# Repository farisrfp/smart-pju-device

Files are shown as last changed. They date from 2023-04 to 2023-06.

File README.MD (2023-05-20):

# **SMART PJU X-CAMP**

_Created by [Faris Rafi](https://www.linkedin.com/in/farisrafp/), last updated on 20 May 2023_

## **About SMART PJU**

This Smart PJU is a continuation of X-Bright with the addition of new features such as communication using LoRa, the use of new sensors, and the use of new modules. This Smart PJU also uses the concept of IoT (Internet of Things) which allows users to control this street lamp through the dashboard provided.

### **Wiring Diagram**

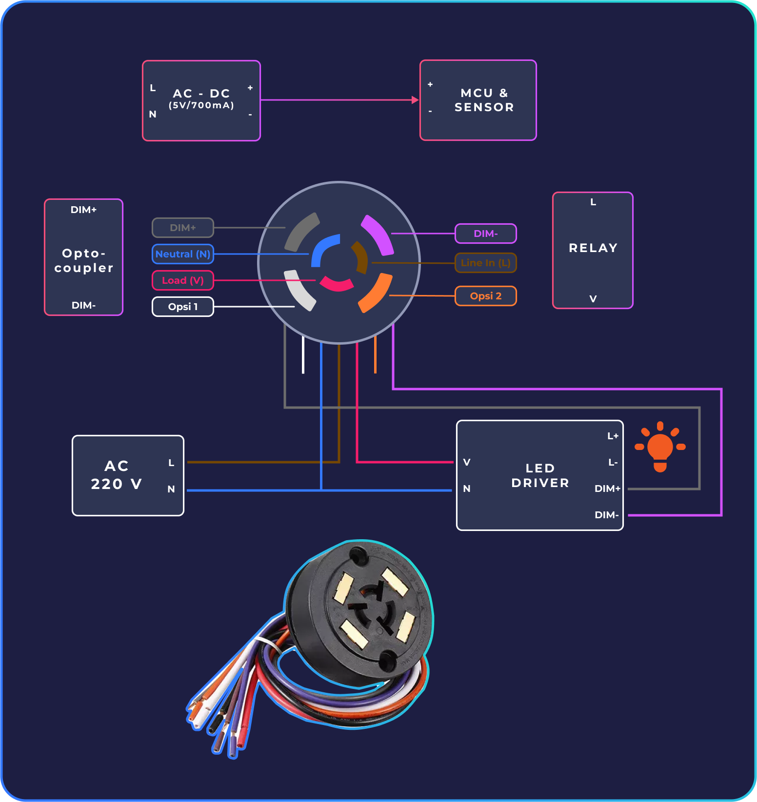
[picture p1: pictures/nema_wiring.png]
wiring


### **Hardware**

|               Controller V2               |
| :---------------------------------------: |
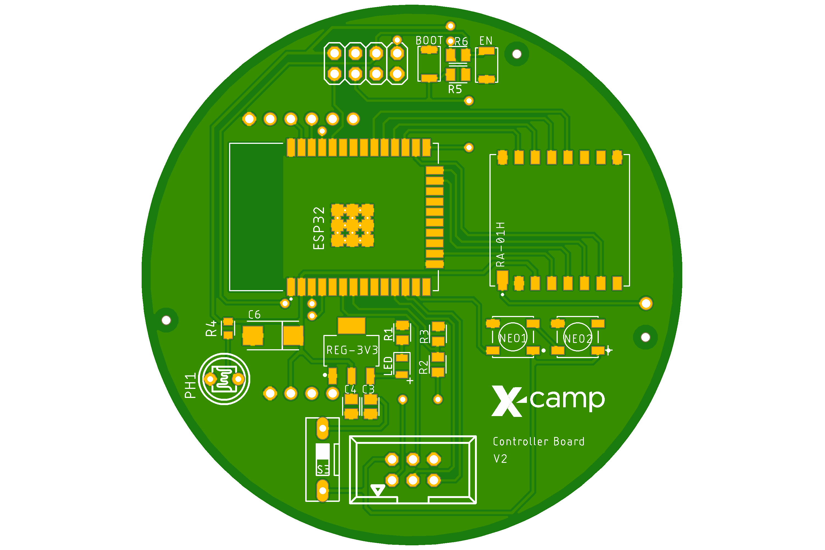
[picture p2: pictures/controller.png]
controller
|  |

|            Power V2             |
| :-----------------------------: |
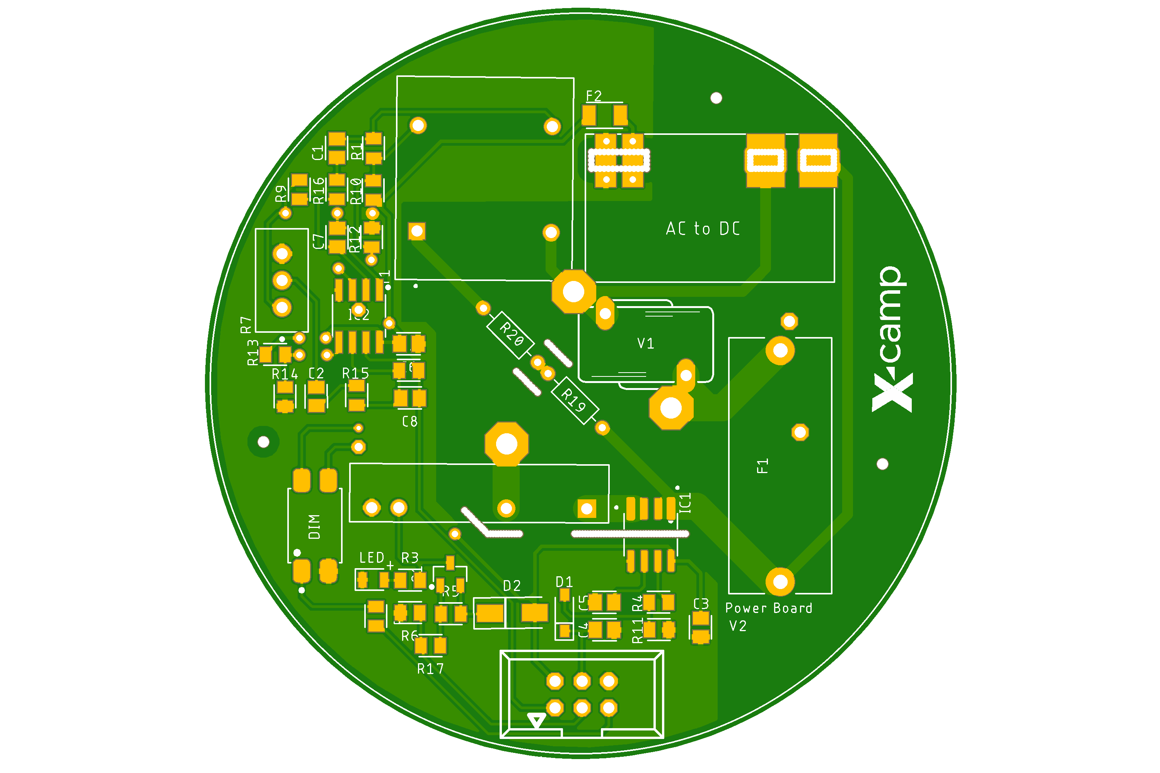
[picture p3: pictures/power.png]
power
|  |

Documentation can be seen [here](./hardware/)

### **Firmware**

Here is the sensor diagram and pinout used on Controller V2.

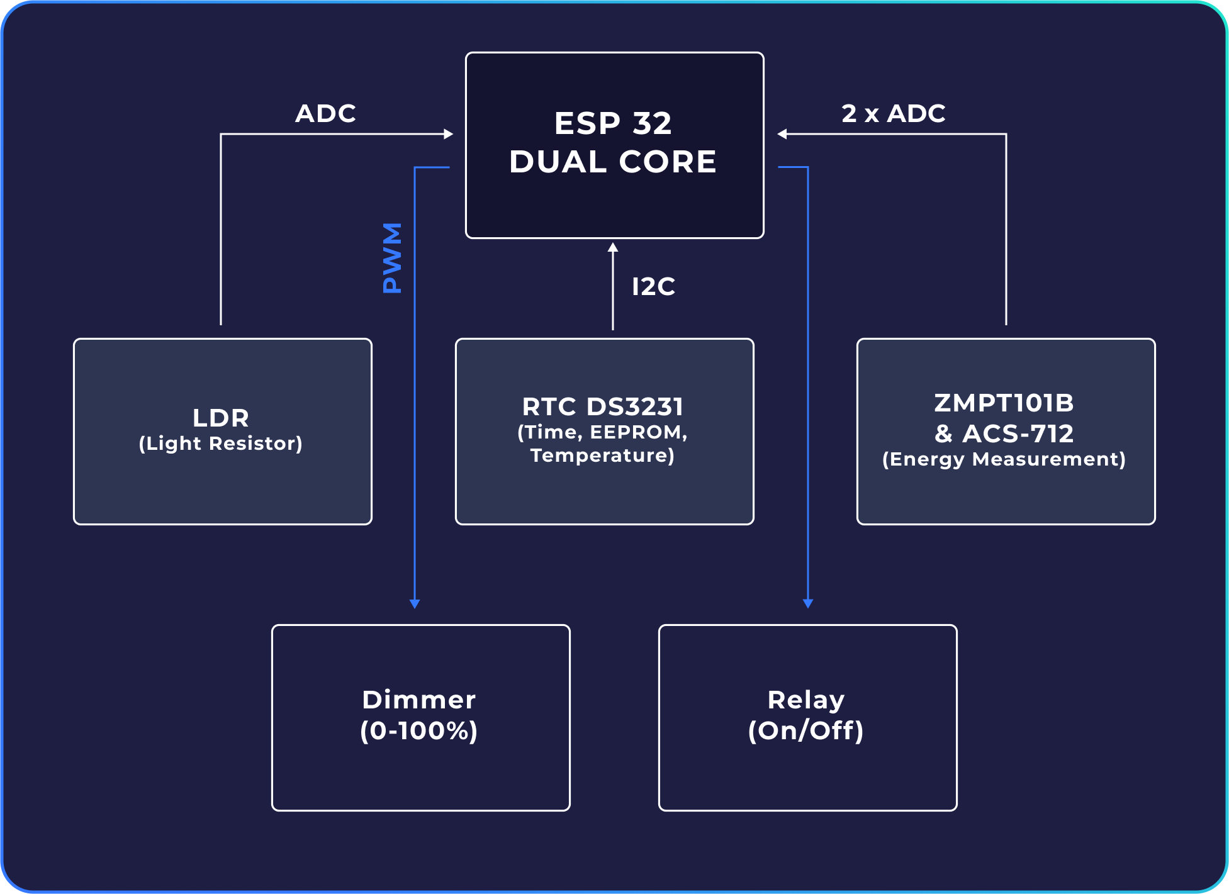
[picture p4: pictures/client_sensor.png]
sensor


Documentation can be seen [here](./firmware/)

## **Contact**

If you have any questions, please contact Faris, the product's designer, by E-mail.

Email : farisrafp@gmail.com

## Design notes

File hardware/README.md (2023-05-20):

# **Hardware Documentation**

## **BOM**

The BoM (Bill of Material) for this project can be seen in the table below.

### **Power Board**

| Designator | Quantity | Description |
| :---: | :---: | :---: |
| AC-DC | 1 |  AC to DC |
| V1 | 1 |  Varistor |
| F1 | 1 | Fuse Holder |
| F2 | 1 |  Fuse PTC |
| DIM | 1 | PC817 |
| IC1 | 1 | ACS712-05B  |
| IC2 | 1 | LM358N |
| T1 | 1 |  ZMPT101B |
| SSR | 1 |  G3MB-202P  |

**Passive Components**

| Designator | Quantity |  Package  |  Value  |
| :---: | :---: | :---: | :-----: |
| Q1 | 1 |  SOT-23 | SS8550  |
| D1 | 1 |  SOD-123  | 1N4448W |
| D2 | 1 | DO-214AC  | M4 |
| LED | 1 | 0805 |  Blue |
| R7 | 1 | 3296 |  100K |
| R1 | 1 | 0805 | 100 |
| R2 - 3 | 2 | 0805 | 330 |
| R4 | 1 | 0805 | 2K |
| R5 - 6 | 2 | 0805 |  4,7K |
| R8 - 9 | 2 | 0805 |  100K |
|  R10 - 17  | 8 | 0805 | 10K |
|  R19 - 20  | 2 | Axial-7.2 |  330K |
| C1 - 2 | 2 | 0805 | 1u |
| C3 - 4 | 2 | 0805 |  100n |
| C5 - 8 | 4 | 0805 | 1n |

<br>

### **Controller Board**

| Designator | Quantity | Description |
| :---: | :---: | :---: |
| ESP32 | 1 | ESP32-WROOM |
|  REG-3V3 | 1 | AMS1117-3V3 |
| RA-01H | 1 | AI-Thinker RA-01H |
| DS3231 | 1 | RTC DS3231 Module |
| NEO 1 | 2 | WS2812B |
| S1 - 2 | 2 | Micro Button |
| S3 | 1 | DIP Switch |
| PH1 | 1 | Light Dependent Resistor |

**Passive Components**

| Designator | Quantity | Package | Value |
| :---: | :---: | :-----: | :---: |
| LED | 1 |  0805 |  Red  |
| R1 - 2 | 2 |  0805 |  1K |
| R3 | 1 |  0805 |  2K |
| R4 - 6 | 3 |  0805 |  10K  |
| C1 | 1 |  0805 | 100n  |
| C2 | 1 |  0805 |  1u |
| C3 - 4 | 2 |  0805 |  10u  |
| C6 | 1 |  2412 | 100u  |

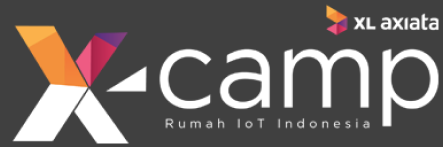
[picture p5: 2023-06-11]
firmware/interface/src/assets/xcamp.png

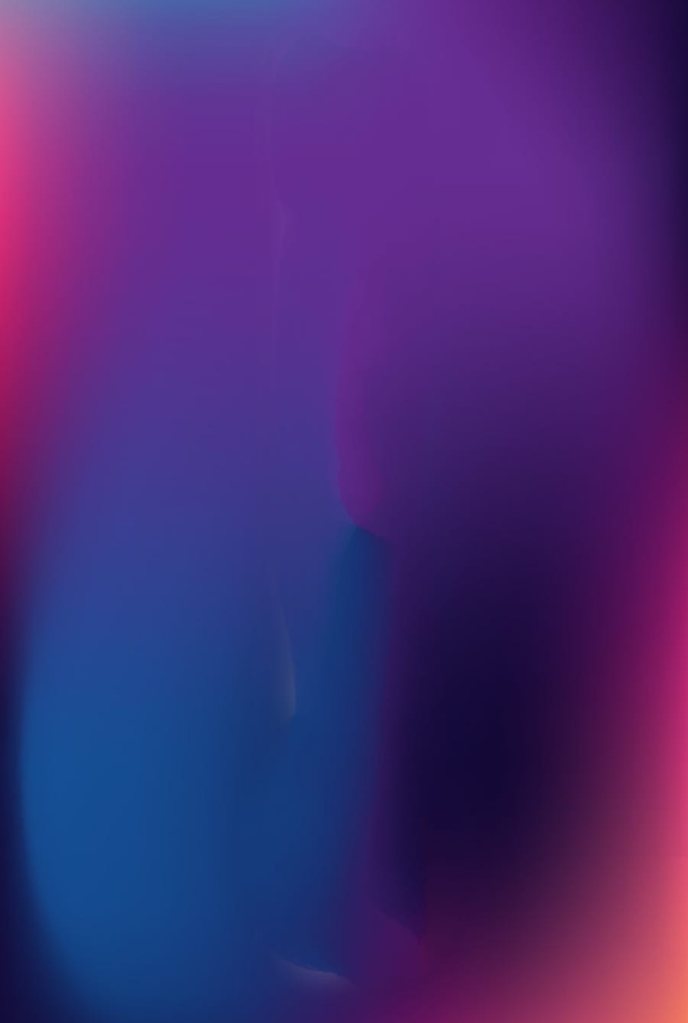
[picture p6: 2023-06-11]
firmware/interface/src/assets/background.png

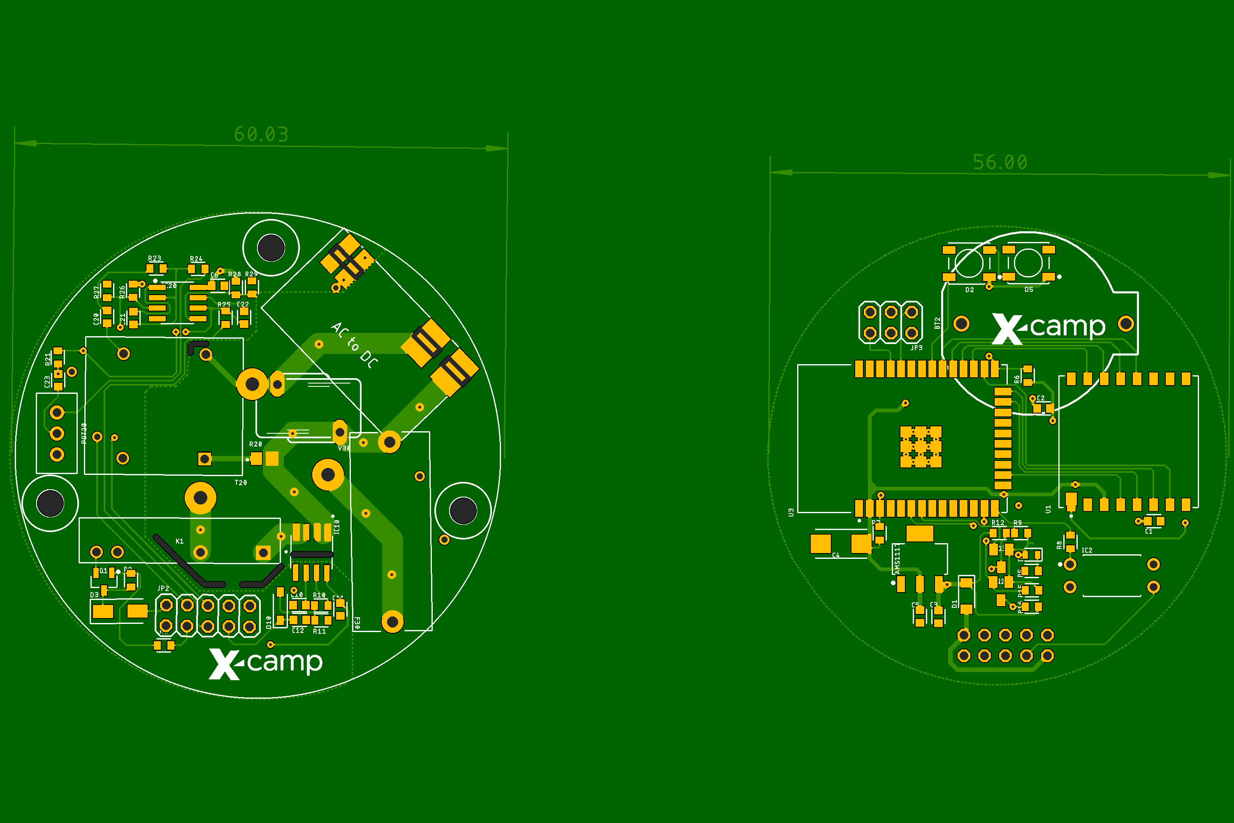
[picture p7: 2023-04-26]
pictures/board_v1.png

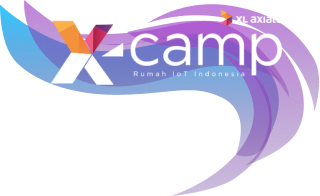
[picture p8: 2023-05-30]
firmware/interface/src/pages/xcamp2.png

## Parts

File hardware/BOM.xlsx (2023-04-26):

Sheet: BOM_Power
No | Designator | Komponen | Value | Package | Qty | Harga | Toko | Link
1 | PS1 | AC to DC | 5V to 700mA | wx-dc12003 | 1 | 14900 | Freelab | Jual 5V 700mA (3.5W) Isolated switch Power Supply Module AC DC 220V to 5V - Standar - Jakarta Pusat - Freelab | Tokopedia (https://www.tokopedia.com/freelab/5v-700ma-3-5w-isolated-switch-power-supply-module-ac-dc-220v-to-5v-pinout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)
2 | V30 | Varistor | 10D471K | Disc | 1 | 1500 | Freelab | Jual Varistor 10D471K MOV 10D471 470V Metal Voltage Dependent Resistor - - Freelab | Tokopedia (https://www.tokopedia.com/freelab/varistor-10d471k-mov-10d471-470v-metal-voltage-dependent-resistor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)
3 | F30 | Fuse Holder | - | 5 x 20 | 1 | 2500 | EasyWare Electronics | Jual Fuse Holder PCB 5x20 Fuse Holder BF-012 10A 250V - Kota Bandung - EasyWare Electronics | Tokopedia (https://www.tokopedia.com/easyware-id/fuse-holder-pcb-5x20-fuse-holder-bf-012-10a-250v?extParam=whid%3D2531933)
 | - | Fuse | 3A | 5 x 20 | 1 | 650 | EasyWare Electronics | Jual Fuse tabung 3A 300mah Sekring kaca fuse 5x20mm 250V - Kota Bandung - EasyWare Electronics | Tokopedia (https://www.tokopedia.com/easyware-id/fuse-tabung-3a-300mah-sekring-kaca-fuse-5x20mm-250v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)
4 | IC10 | ACS712-05B | - | SOIC-8 | 1 | 24000 | toko puwei | Jual ACS712elctr-05B ACS712elctr IC Sensor Arus ACS712 5A SOP8 AH60 - Jakarta Utara - toko puwei | Tokopedia (https://www.tokopedia.com/tokopuwei/acs712elctr-05b-acs712elctr-ic-sensor-arus-acs712-5a-sop8-ah60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)
5 | T20 | ZMPT101B | 1000 : 1000 | - | 1 | 15000 | arduinouno | Jual single phase voltage transformer ZMPT101B 2mA/2mA - Jakarta Barat - arduinouno | Tokopedia (https://www.tokopedia.com/arduinouno/single-phase-voltage-transformer-zmpt101b-2ma2ma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)
6 | IC20 | LM358N | - | SOIC-8 | 1 | 3099 | Lisu Instrument | Jual ORIGINAL Operational Amplifier LM358DT LM358 SOIC-8 STMicroelectronics - Kota Depok - Lisu Instrument | Tokopedia (https://www.tokopedia.com/lisuinstrument/original-operational-amplifier-lm358dt-lm358-soic-8-stmicroelectronics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)
8 | K1 | G3MB-202P | - | - | 1 | 12500 | toko puwei | Jual G3MB-202P-5VDC Solid State Relay SSR OMRON 240V AC DC 2A Load 5V 10mA - Jakarta Utara - toko puwei | Tokopedia (https://www.tokopedia.com/tokopuwei/g3mb-202p-5vdc-solid-state-relay-ssr-omron-240v-ac-dc-2a-load-5v-10ma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)
9 | POT20 | Trimpot | 100K | 3296 | 1 | 1250 | toko puwei | Jual 3296W 104 100k ohm Multiturn Trimpot Trimmer Variable Resistor VR AM88 - Jakarta Utara - toko puwei | Tokopedia (https://www.tokopedia.com/tokopuwei/3296w-104-100k-ohm-multiturn-trimpot-trimmer-variable-resistor-vr-am88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)
10 | Q1 | Transistor | SS8550 | SOT-23 | 1 | 499 | Lisu Instrument | Jual SS8550 8550 Y2 SOT-23 -1.5A -40V - Generic Biasa - Kota Depok - Lisu Instrument | Tokopedia (https://www.tokopedia.com/lisuinstrument/ss8550-8550-y2-sot-23-1-5a-40v-hottech?extParam=whid%3D580205)
11 | D10 | Diode | 1N4448W | SOD-123 | 1 | 1499 | Lisu Instrument | Jual IN4148 1N4148WS 1N4148 SOD-123 T4 Switching Diode SOD123 - Hottech - Kota Depok - Lisu Instrument | Tokopedia (https://www.tokopedia.com/lisuinstrument/in4148-1n4148ws-1n4148-sod-123-t4-switching-diode-sod123-diodes-inc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)
12 | D3 | Diode | M4 | DO-214AC | 1 | 549 | Lisu Instrument | Jual S1M DO-214AC SMA 1A 1KV General-Purpose Rectifiers - Kota Depok - Lisu Instrument | Tokopedia (https://www.tokopedia.com/lisuinstrument/s1m-do-214ac-sma-1a-1kv-general-purpose-rectifiers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)
13 | R24, R25 | Resistor | 100K | 0603 | 2 | 100 | Lisu Instrument | Jual SMD 100K Resistor 0603 1608 1% SMT 47KOhm - Kota Depok - Lisu Instrument | Tokopedia (https://www.tokopedia.com/lisuinstrument/smd-100k-resistor-0603-1608-1-smt-47kohm?extParam=whid%3D580205)
14 | R1, R2, R11, R21, R23, R26, R27, R28, R29 | Resistor | 10K | 0603 | 9 | 250 | cosmic.id | Jual Resistor 10K 0603 SMD 10 K Ohm 10 KiloOhm Kilo Ohm 5% SMD0603 - Kab. Bandung Barat - cosmic.id | Tokopedia (https://www.tokopedia.com/cosmic-iot/resistor-10k-0603-smd-10-k-ohm-10-kiloohm-kilo-ohm-5-smd0603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)
15 | R10 | Resistor | 2K | 0603 | 1 | 100 | Lisu Instrument | Jual 2K 0603 ±1% Thick Film Resistors SMD Chip Resistor 30B 2001 - - Lisu Instrument | Tokopedia (https://www.tokopedia.com/lisuinstrument/2k-0603-1-thick-film-resistors-smd-chip-resistor-30b-2001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)
16 | R20 | Resistor | 820K | 1206 | 1 | 100 | Lisu Instrument | Jual 820K 0805 ±1% Thick Film Resistors SMD Chip Resistor 8203 824 - Kota Depok - Lisu Instrument | Tokopedia (https://www.tokopedia.com/lisuinstrument/820k-0805-1-thick-film-resistors-smd-chip-resistor-8203-824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)
17 | R22 | Resistor | 100 | 1206 | 1 | 100 | Lisu Instrument | Jual SMD 100R Resistor 1206 1% SMT 100 Ohm - Kota Depok - Lisu Instrument | Tokopedia (https://www.tokopedia.com/lisuinstrument/smd-100r-resistor-1206-1-smt-100-ohm?extParam=whid%3D580205)
18 | C10 | Capacitor | 1n | 0603 | 1 | 199 | Lisu Instrument | Jual 1nF ±10% 50V X7R 0603 Multilayer Ceramic Capacitors MLCC SMD SMT - Kota Depok - Lisu Instrument | Tokopedia (https://www.tokopedia.com/lisuinstrument/1nf-10-50v-x7r-0603-multilayer-ceramic-capacitors-mlcc-smd-smt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)
19 | C11, C12 | Capacitor | 100n | 0603 | 2 | 149 | Lisu Instrument | Jual 100nF ±10% 25V X7R 0603 Multilayer Ceramic Capacitors MLCC SMD SMT - Kota Depok - Lisu Instrument | Tokopedia (https://www.tokopedia.com/lisuinstrument/100nf-10-25v-x7r-0603-multilayer-ceramic-capacitors-mlcc-smd-smt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)
20 | C6, C21, C22 | Capacitor | 100p | 0603 | 3 | 199 | Lisu Instrument | Jual 100pF ±5% 50V C0G 0603 Multilayer Ceramic Capacitors MLCC SMD SMT - Kota Depok - Lisu Instrument | Tokopedia (https://www.tokopedia.com/lisuinstrument/100pf-5-50v-c0g-0603-multilayer-ceramic-capacitors-mlcc-smd-smt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)
21 | C20, C23 | Capacitor | 1u | 0603 | 2 | 599 | Lisu Instrument | Jual 1uF ±10% 50V X7R 0603 1608(mm) SMD Ceramic Capacitors MLCC Fenghua - Kota Depok - Lisu Instrument | Tokopedia (https://www.tokopedia.com/lisuinstrument/1uf-10-50v-x7r-0603-1608-mm-smd-ceramic-capacitors-mlcc-fenghua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)
 |  |  |  |  | Total | 60192

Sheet: BOM_Controller
No | Designator | Komponen | Value | Package | Qty | Harga | Toko | Link
1 | U3 | ESP32 WROOM 32D | - | - | 1 | 49900 | Freelab | Jual Modul ESP-WROOM-32 Module ESP32 Dual Core WiFi Bluetooth SPI Flash 4MB - Jakarta Pusat - Freelab | Tokopedia (https://www.tokopedia.com/freelab/modul-esp-wroom-32-module-esp32-dual-core-wifi-bluetooth-spi-flash-4mb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)
2 | AMS1117 | AMS1117 3V3 | 3V3 | SOT-223 | 1 | 800 | EasyWare Electronics | Jual AMS1117-3.3V AMS1117 SOT-223 IC Voltage regulator - Kota Bandung - EasyWare Electronics | Tokopedia (https://www.tokopedia.com/easyware-id/ams1117-3-3v-ams1117-sot-223-ic-voltage-regulator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)
3 | U1 | AI-Thinker RA-01H | - | - | 1 | 86900 | Freelab | Jual Ai Thinker LoRa RA-01H SX1276 868MHz Cocok Indonesia AS923-2 Antares - Jakarta Pusat - Freelab | Tokopedia (https://www.tokopedia.com/freelab/ai-thinker-lora-ra-01h-sx1276-868mhz-cocok-indonesia-as923-2-antares)
4 | IC1 | DS3231 | - | SOIC-16 | 1 | 39000 | CNC STORE YOGYAKARTA | Jual DS3231SN Ds3231 SN Sop16 Sop-16 Serial I2c Rtc Real Time Clock Ic - Kab. Bantul - CNC STORE YOGYAKARTA | Tokopedia (https://www.tokopedia.com/cncstorejogja/ds3231sn-ds3231-sn-sop16-sop-16-serial-i2c-rtc-real-time-clock-ic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)
5 | U2 | AT24C32N | - | SOIC-8 | 1 | 1400 | toko powei | Jual 24C32 AT24C32 AT24C32N AT24C32AN SOP-8 BX57 - Jakarta Utara - toko puwei | Tokopedia (https://www.tokopedia.com/tokopuwei/24c32-at24c32-at24c32n-at24c32an-sop-8-bx57?extParam=whid%3D366097)
6 | BT2 | Battery Holder CR2032 | - | - | 1 | 550 | Freelab | Jual Socket Soket Tempat Holder Case Battery Baterai Kancing CR2032 - Jakarta Pusat - Freelab | Tokopedia (https://www.tokopedia.com/freelab/socket-soket-tempat-holder-case-battery-baterai-kancing-cr2032)
7 | IC2 | PC817 | - | SOIC-16 | 1 | 650 | Freelab | Jual IC Chip SMD PC 817 PC817 EL817C FL817C SOP-4 Optocoupler Isolator Ori - Jakarta Pusat - Freelab | Tokopedia (https://www.tokopedia.com/freelab/ic-chip-smd-pc-817-pc817-el817c-fl817c-sop-4-optocoupler-isolator-ori)
8 | D2, D5 | WS2812B | - | - | 2 | 2400 | cosmic.id | Jual LED RGB WS2812B WS2812 Chip SMD 5050 5V 5 VOLT - Kab. Bandung Barat - cosmic.id | Tokopedia (https://www.tokopedia.com/cosmic-iot/led-rgb-ws2812b-ws2812-chip-smd-5050-5v-5-volt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)
9 | D4 | LED | Blue | 0603 | 1 | 100 | Lisu Instrument | Jual 0603 SMD LED SMT Ultra Bright 5 Pilihan Warna - Biru - Kota Depok - Lisu Instrument | Tokopedia (https://www.tokopedia.com/lisuinstrument/0603-smd-led-smt-ultra-bright-5-pilihan-warna-biru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)
12 | Q2, Q3 | Mosfet | BSS138 | SOT23 | 2 | 1800 | Lisu Instrument | Toko Lisu Instrument Online - Produk Lengkap & Harga Terbaik | Tokopedia (https://www.tokopedia.com/lisuinstrument/bss138-j1-50v-200ma-n-channel-mosfet-bss138lt-sot-23-original-onsemi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)
13 | D1 | Diode | 1N5819 | SOD-323 | 1 | 499 | Lisu Instrument | Jual 1N5819 1N5819WS S4 40V 350mA Schottky Barrier Diode SOD-323 JSMicro - Kota Depok - Lisu Instrument | Tokopedia (https://www.tokopedia.com/lisuinstrument/1n5819-1n5819ws-s4-40v-350ma-schottky-barrier-diode-sod-323-jsmicro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)
14 | R17, R18, R19, R31, R32, R33 | Resistor | 10K | 1206 | 15 | 100 | Lisu Instrument | Jual SMD 10K Resistor 1206 1% SMT 10KOhm - 1 buah - Kota Depok - Lisu Instrument | Tokopedia (https://www.tokopedia.com/lisuinstrument/smd-10k-resistor-1206-1-smt-10kohm-1-buah?extParam=whid%3D580205)
15 | R6, R7, R9, R12, R15,R16 | Resistor | 10K | 0603 | 15 | 250 | cosmic.id | Jual Resistor 10K 0603 SMD 10 K Ohm 10 KiloOhm Kilo Ohm 5% SMD0603 - Kab. Bandung Barat - cosmic.id | Tokopedia (https://www.tokopedia.com/cosmic-iot/resistor-10k-0603-smd-10-k-ohm-10-kiloohm-kilo-ohm-5-smd0603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)
16 | R5, R8 | Resistor | 100 | 0603 | 2 | 100 | Lisu Instrument | Jual SMD 100R Resistor 0603 1% SMT 100Ω Ohm - Kota Depok - Lisu Instrument | Tokopedia (https://www.tokopedia.com/lisuinstrument/smd-100r-resistor-0603-1-smt-100-ohm?extParam=whid%3D580205)
17 | C4 | Capacitor | 100µ | 2412 | 1 | 7800 | Lisu Instrument | Jual 100uF 16V ±20% 6032 2312 Tantalum Capacitors - Kota Depok - Lisu Instrument | Tokopedia (https://www.tokopedia.com/lisuinstrument/100uf-16v-20-6032-2312-tantalum-capacitors?extParam=whid%3D580205)
18 | C3, C5 | Capacitor | 10µ | 0603 | 2 | 249 | Lisu Instrument | Jual 10uF ±10% 6.3V X5R 0603 1608(mm) Multilayer Ceramic Capacitors SMD SMT - Kota Depok - Lisu Instrument | Tokopedia (https://www.tokopedia.com/lisuinstrument/10uf-10-6-3v-x5r-0603-1608-mm-multilayer-ceramic-capacitors-smd-smt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)
19 | C2 | Capacitor | 100n | 0603 | 1 | 149 | Lisu Instrument | Jual 100nF ±10% 25V X7R 0603 Multilayer Ceramic Capacitors MLCC SMD SMT - Kota Depok - Lisu Instrument | Tokopedia (https://www.tokopedia.com/lisuinstrument/100nf-10-25v-x7r-0603-multilayer-ceramic-capacitors-mlcc-smd-smt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)
20 | C1 | Capacitor | 1µ | 0603 | 1 | 599 | Lisu Instrument | Jual 1uF ±10% 50V X7R 0603 1608(mm) SMD Ceramic Capacitors MLCC Fenghua - Kota Depok - Lisu Instrument | Tokopedia (https://www.tokopedia.com/lisuinstrument/1uf-10-50v-x7r-0603-1608-mm-smd-ceramic-capacitors-mlcc-fenghua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)
 |  |  |  |  | Total | 193246

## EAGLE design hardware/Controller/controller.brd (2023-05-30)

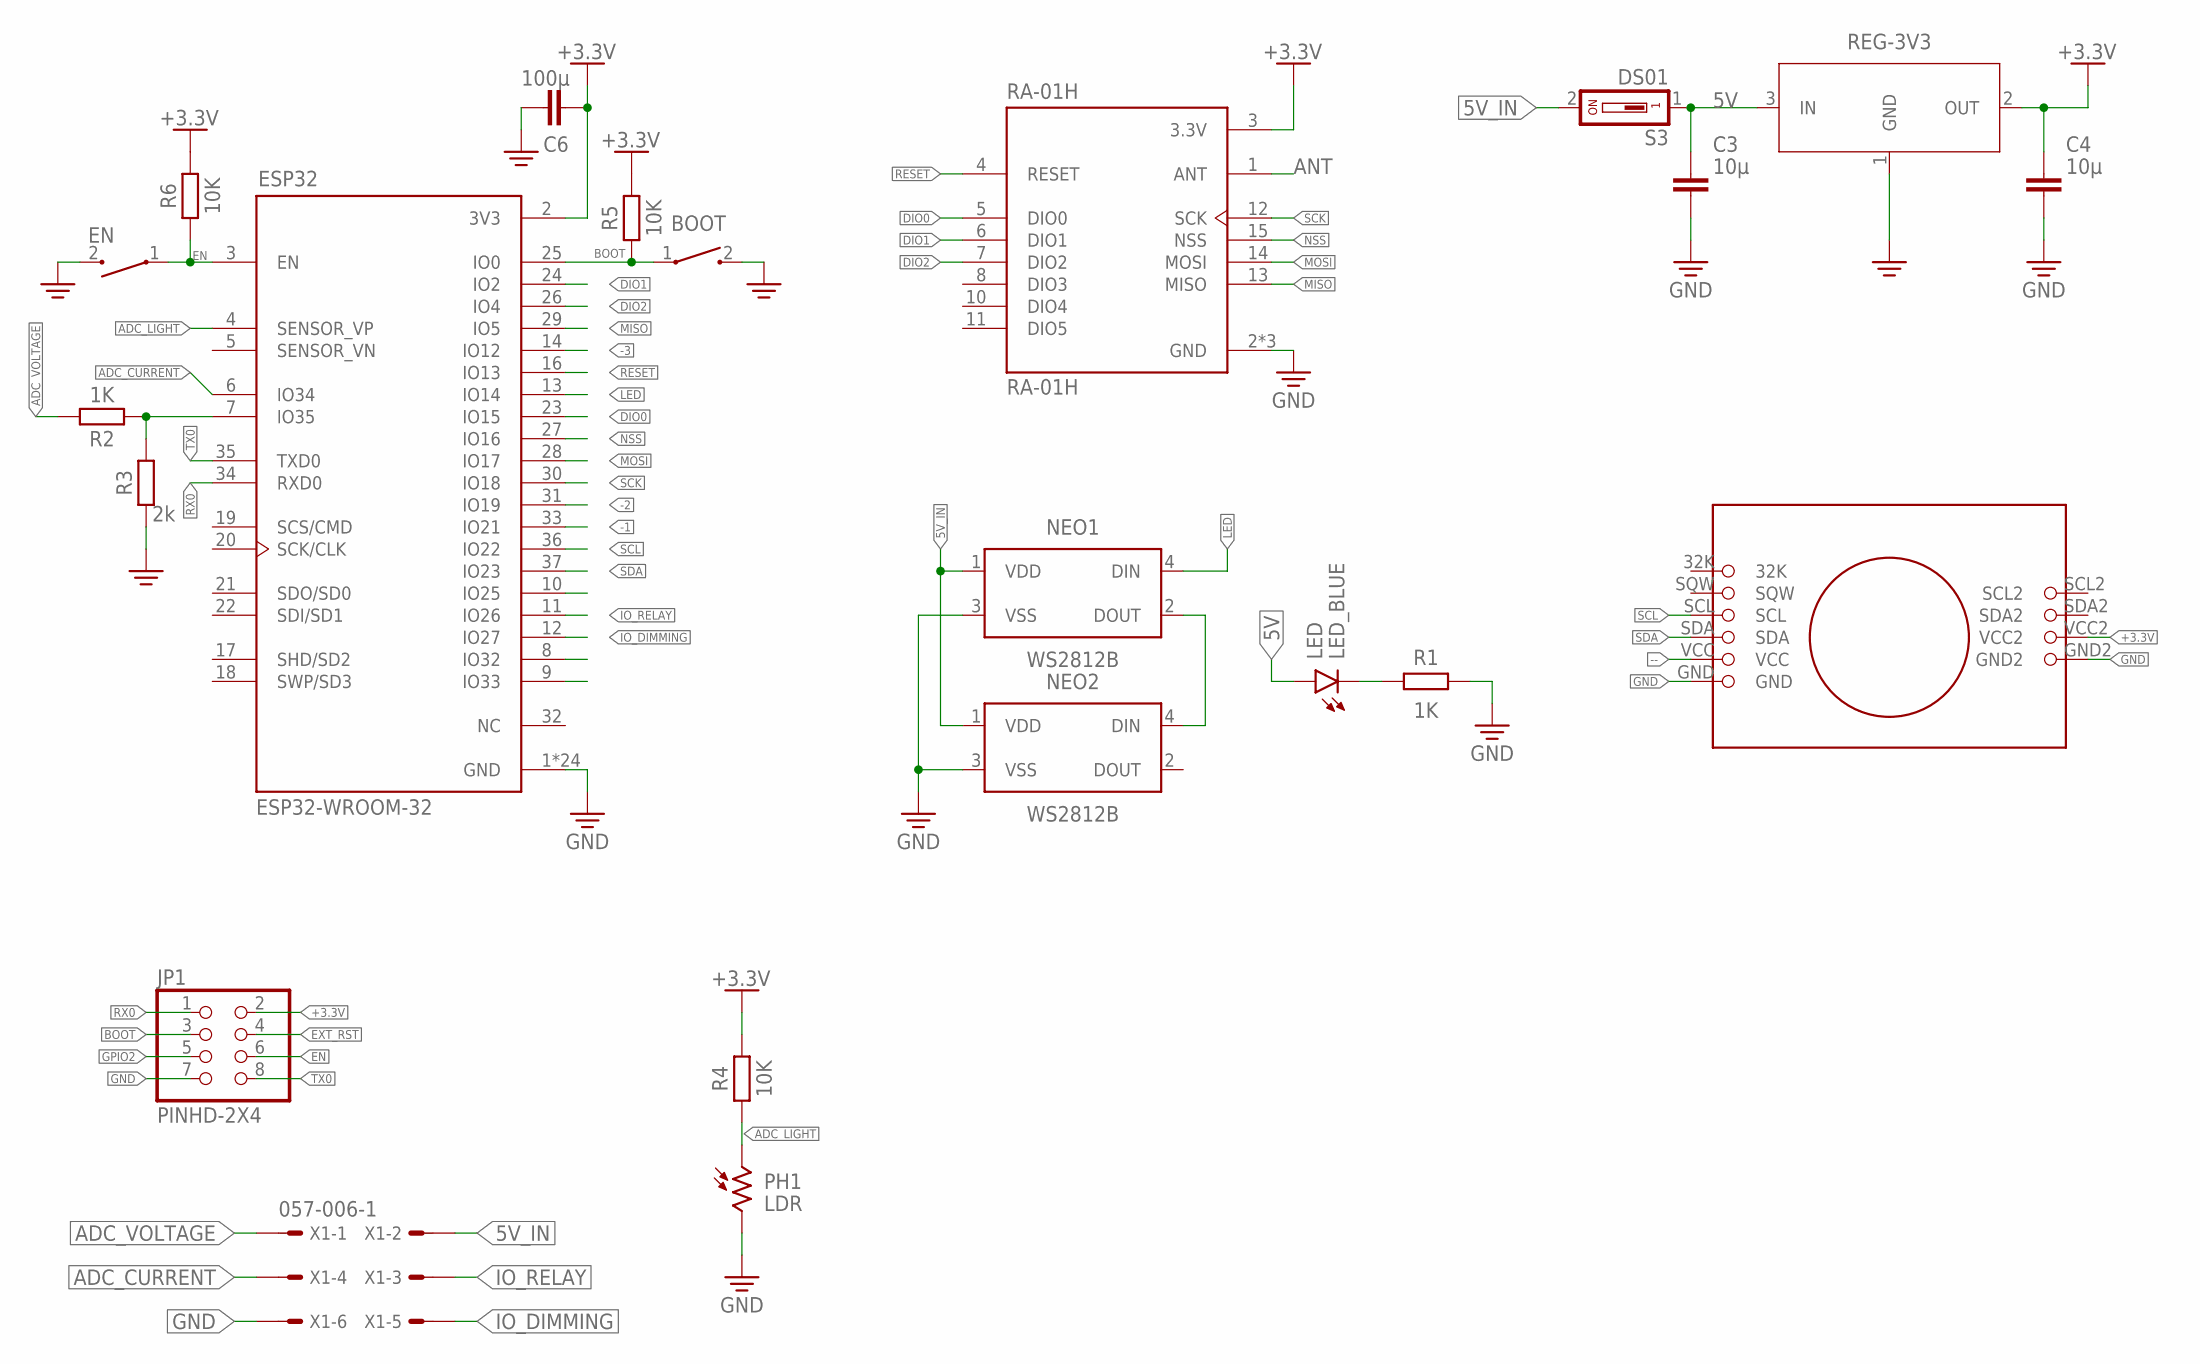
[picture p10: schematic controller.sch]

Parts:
BOOT: SWITCH; SW_1437566-3
C3, C4: 10µ; CAPC2012X110
C6: 100µ; CAPM6032X280
EN: SWITCH; SW_1437566-3
ESP32: ESP32-WROOM-32; MODULE_ESP32-WROOM-32
JP1: PINHD-2X4; 2X04
LED: LED_BLUE; LEDC2012X110N_FLAT-B
NEO1, NEO2: WS2812B
PH1: LDR; T0-46-A10XX
R1, R2: 1K; RESC2012X65
R3: 2k; RESC2012X65
R4: 10K; RESC1608X60
R5, R6: 10K; RESC2012X65
RA-01H: RA-01H
REG-3V3: NCP1117ST33T3G; SOT230P700X170-4
S3: DS01; DS-01
U$1: DS3231_MODULE
X1: 057-006-1

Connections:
5V: C3.1, LED.A, REG-3V3.3 (IN), S3.1
5V_IN: NEO1.1 (VDD), NEO2.1 (VDD), S3.2, X1.2
+3.3V: C4.1, C6.1, ESP32.2 (3V3), JP1.2, R4.2, R5.2, R6.2, RA-01H.3 (3.3V), REG-3V3.2 (OUT), U$1.VCC2
-1: ESP32.33 (IO21)
-2: ESP32.31 (IO19)
-3: ESP32.14 (IO12)
--: U$1.VCC
ADC_CURRENT: ESP32.6 (IO34), X1.4
ADC_LIGHT: ESP32.4 (SENSOR_VP), PH1.1, R4.1
ADC_VOLTAGE: R2.2, X1.1
ANT: RA-01H.1 (ANT)
BOOT: BOOT.1, ESP32.25 (IO0), JP1.3, R5.1
DIO0: ESP32.23 (IO15), RA-01H.5 (DIO0)
DIO1: ESP32.24 (IO2), RA-01H.6 (DIO1)
DIO2: ESP32.26 (IO4), RA-01H.7 (DIO2)
EN: EN.1, ESP32.3 (EN), JP1.6, R6.1
EXT_RST: JP1.4
GND: BOOT.2, C3.2, C4.2, C6.2, EN.2, ESP32.1 (GND), ESP32.15 (GND), ESP32.38 (GND), ESP32.39_1 (GND), ESP32.39_2 (GND), ESP32.39_3 (GND), ESP32.39_4 (GND), ESP32.39_5 (GND), ESP32.39_6 (GND), ESP32.39_7 (GND), ESP32.39_8 (GND), ESP32.39_9 (GND), ESP32.39_10 (GND), ESP32.39_11 (GND), ESP32.39_12 (GND), ESP32.39_13 (GND), ESP32.39_14 (GND), ESP32.39_15 (GND), ESP32.39_16 (GND), ESP32.39_17 (GND), ESP32.39_18 (GND), ESP32.39_19 (GND), ESP32.39_20 (GND), ESP32.39_21 (GND), JP1.7, NEO1.3 (VSS), NEO2.3 (VSS), PH1.2, R1.2, R3.1, RA-01H.2 (GND), RA-01H.9 (GND), RA-01H.16 (GND), REG-3V3.1 (GND), U$1.GND, U$1.GND2, X1.6
GPIO2: JP1.5
IO_DIMMING: ESP32.12 (IO27), X1.5
IO_RELAY: ESP32.11 (IO26), X1.3
LED: ESP32.13 (IO14), NEO1.4 (DIN)
MISO: ESP32.29 (IO5), RA-01H.13 (MISO)
MOSI: ESP32.28 (IO17), RA-01H.14 (MOSI)
unnamed: ESP32.7 (IO35), R2.1, R3.2
unnamed: NEO1.2 (DOUT), NEO2.4 (DIN)
unnamed: LED.C, R1.1
NSS: ESP32.27 (IO16), RA-01H.15 (NSS)
RESET: ESP32.16 (IO13), RA-01H.4 (RESET)
RX0: ESP32.34 (RXD0), JP1.1
SCK: ESP32.30 (IO18), RA-01H.12 (SCK)
SCL: ESP32.36 (IO22), U$1.SCL
SDA: ESP32.37 (IO23), U$1.SDA
TX0: ESP32.35 (TXD0), JP1.8

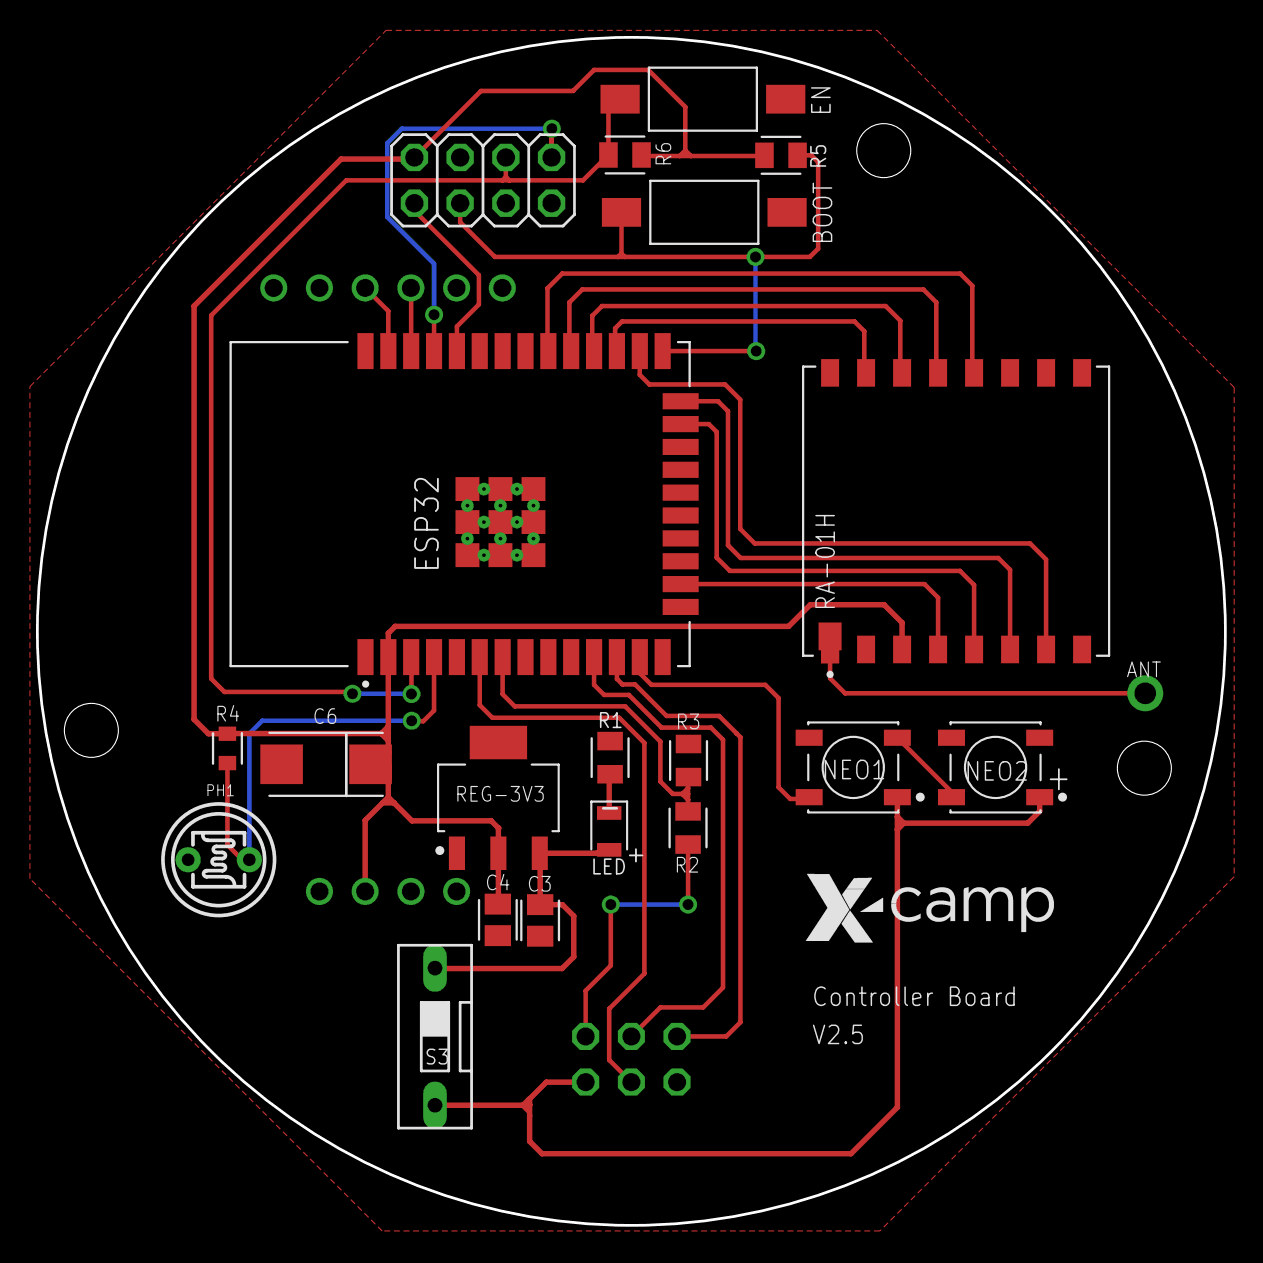
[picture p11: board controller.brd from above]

Board: 2 copper layers, 66.0 x 66.0 mm, 22 parts (1 on the bottom side), 27 nets.

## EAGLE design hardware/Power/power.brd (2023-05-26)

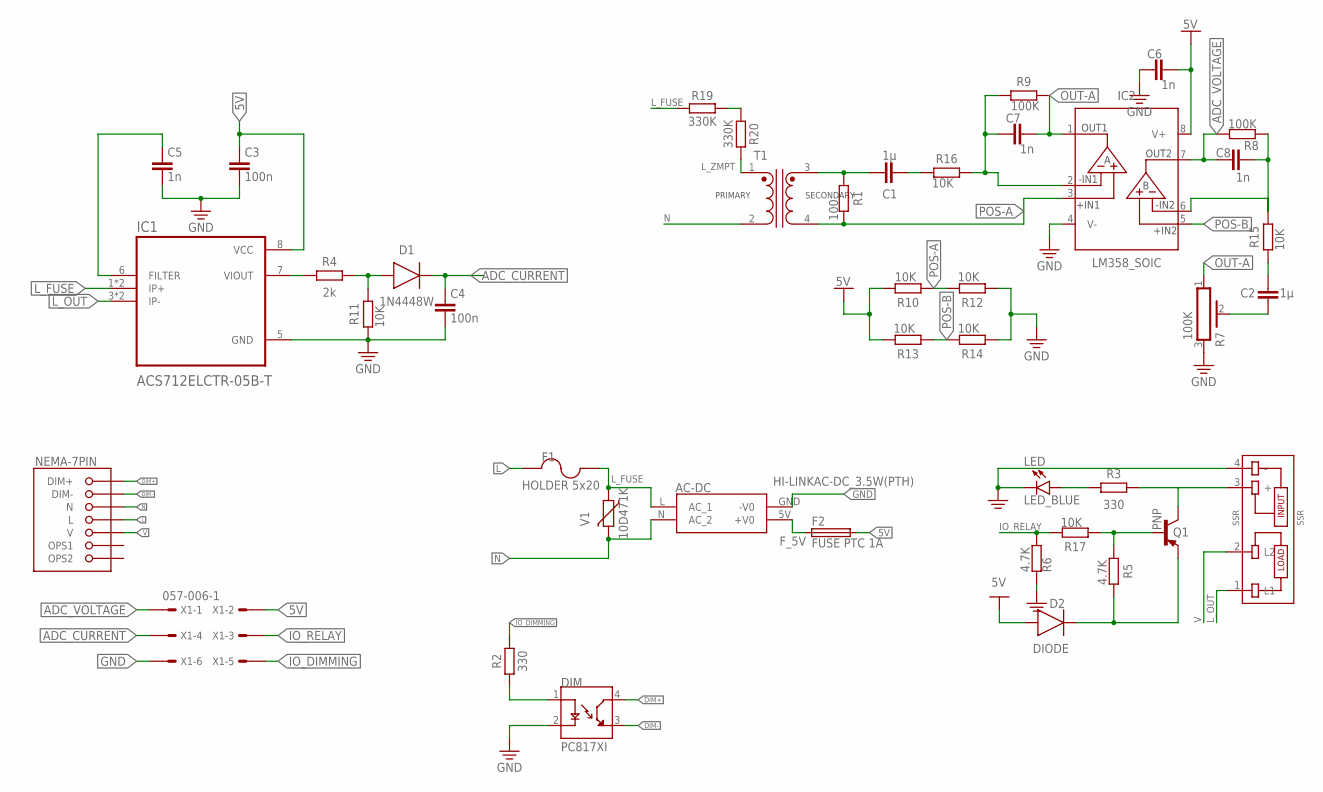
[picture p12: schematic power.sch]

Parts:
AC-DC: HI-LINKAC-DC_3.5W(PTH); AC-DC_3.5W(PTH)
C1, C2: 1µ; CAPC2012X110
C3, C4: 100n; CAPC2012X110
C5, C6, C7, C8: 1n; CAPC2012X110
D1: 1N4448W; SOD3715X135
D2: DIODE; DIOM5226X290N
DIM: PC817XI; SOIC254P975X460-4N
F1: HOLDER 5x20; 4527
F2: FUSE PTC 1A; FUSC3215X82N
IC1: ACS712ELCTR-05B-T; SOIC127P600X175-8N@1
IC2: LM358_SOIC; SOIC127P600X175-8N
LED: LED_BLUE; LEDC2012X110N_FLAT-B
NEMA-7PIN: NEMA-7P
Q1: PNP; SOT95P237X112-3N
R1: 100; RESC2012X65
R2, R3: 330; RESC2012X65
R4: 2k; RESC2012X65
R5, R6: 4.7K; RESC2012X65
R7: 100K; PV36W
R8, R9: 100K; RESC2012X65
R10, R11, R12, R13, R14, R15, R16, R17: 10K; RESC2012X65
R19, R20: 330K; RESAD724W46L381D178B
SSR: SSR; SSR_G3MB-202P
T1: ZMPT101B
V1: 10D471K; MOV-10D561
X1: 057-006-1

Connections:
5V: C3.1, C6.2, D2.2 (A), F2.2, IC1.8 (VCC), IC2.8 (V+), R10.2, R13.2, X1.2
ADC_CURRENT: C4.1, D1.1 (C), X1.4
ADC_VOLTAGE: C8.1, IC2.7 (OUT2), R8.2, X1.1
DIM+: DIM.4 (CT), NEMA-7PIN.DIM+
DIM-: DIM.3 (ET), NEMA-7PIN.DIM-
F_5V: AC-DC.5V (+V0), F2.1
GND: AC-DC.GND (-V0), C3.2, C4.2, C5.2, C6.1, DIM.2 (C), IC1.5 (GND), IC2.4 (V-), LED.C, R6.2, R7.3, R11.1, R12.1, R14.1, SSR.4 (-), X1.6
IO_DIMMING: R2.2, X1.5
IO_RELAY: R6.1, R17.2, X1.3
L: F1.1, NEMA-7PIN.L
L_FUSE: AC-DC.L (AC_1), F1.2, IC1.1 (IP+), IC1.2 (IP+), R19.1, V1.1
L_OUT: IC1.3 (IP-), IC1.4 (IP-), SSR.1 (L1)
L_ZMPT: R20.2, T1.1
N: AC-DC.N (AC_2), NEMA-7PIN.N, T1.2, V1.2
unnamed: C1.1, R1.1, T1.3
unnamed: C1.2, R16.1
unnamed: IC1.7 (VIOUT), R4.1
unnamed: R19.2, R20.1
unnamed: C7.1, IC2.2 (-IN1), R9.1, R16.2
unnamed: D1.2 (A), R4.2, R11.2
unnamed: C5.1, IC1.6 (FILTER)
unnamed: D2.1 (C), Q1.2 (E), R5.2
unnamed: Q1.1 (B), R5.1, R17.1
unnamed: Q1.3 (C), R3.2, SSR.3 (+)
unnamed: C8.2, IC2.6 (-IN2), R8.1, R15.2
unnamed: C2.2, R15.1
unnamed: C2.1, R7.2
unnamed: LED.A, R3.1
unnamed: DIM.1 (A), R2.1
OUT-A: C7.2, IC2.1 (OUT1), R7.1, R9.2
POS-A: IC2.3 (+IN1), R1.2, R10.1, R12.2, T1.4
POS-B: IC2.5 (+IN2), R13.1, R14.2
V: NEMA-7PIN.V, SSR.2 (L2)

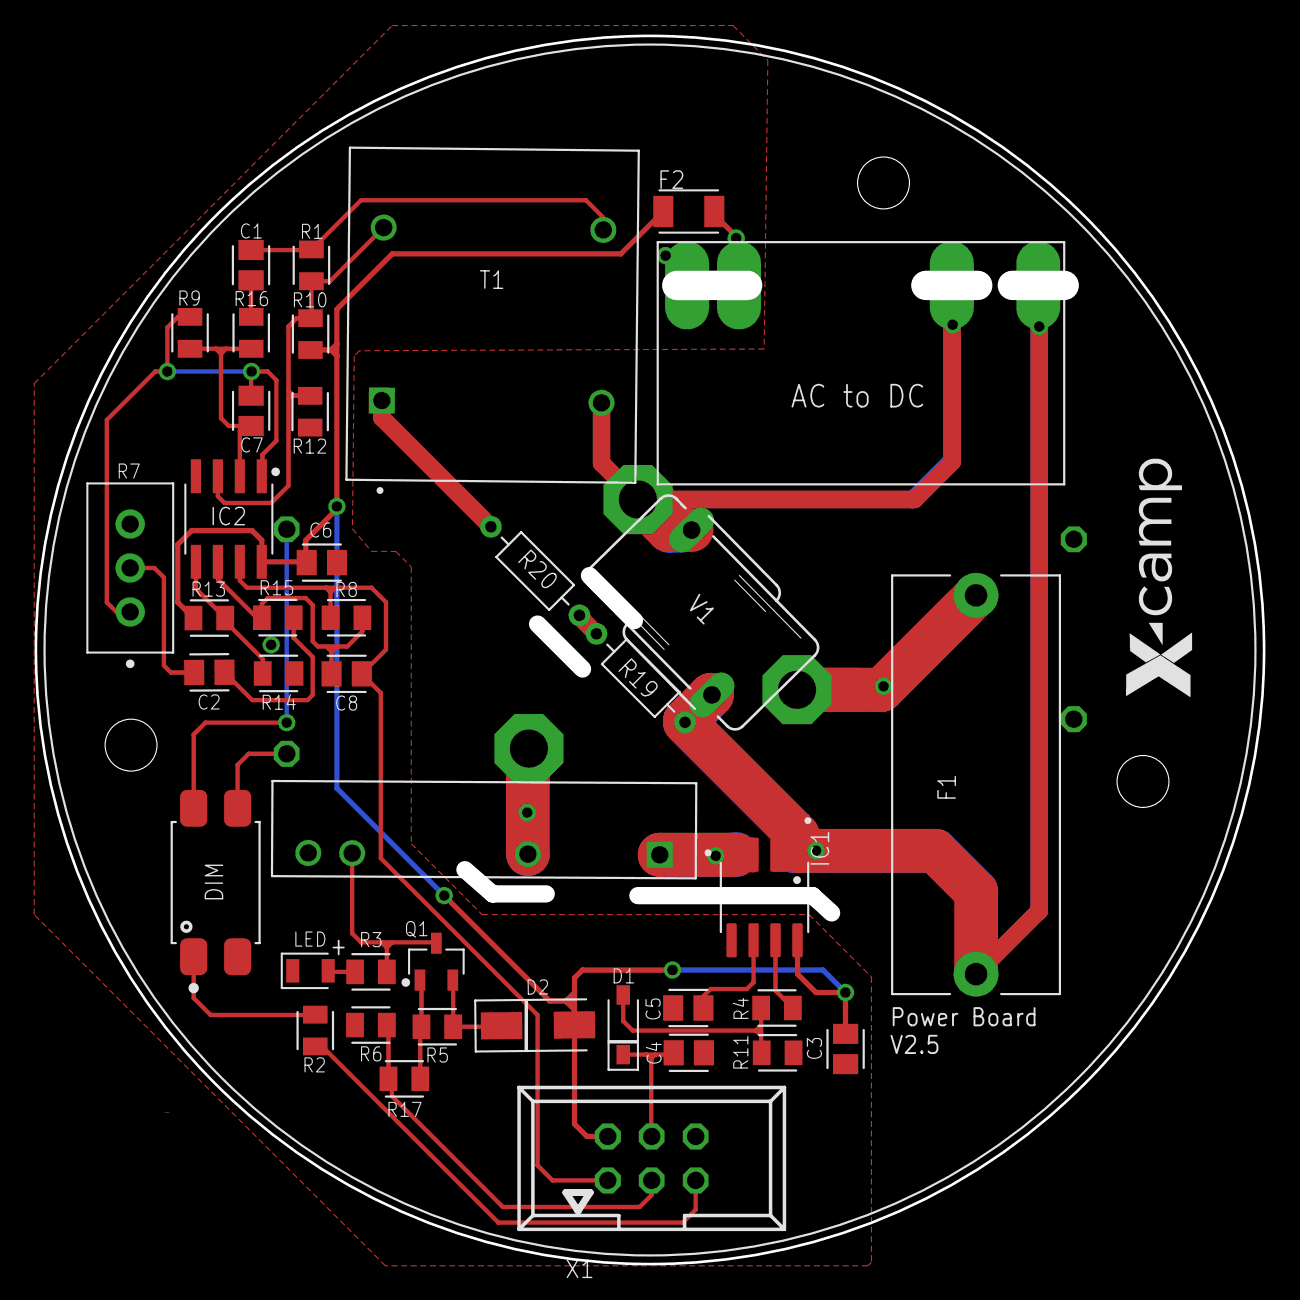
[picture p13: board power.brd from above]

Board: 2 copper layers, 71.0 x 71.0 mm, 42 parts (0 on the bottom side), 33 nets.

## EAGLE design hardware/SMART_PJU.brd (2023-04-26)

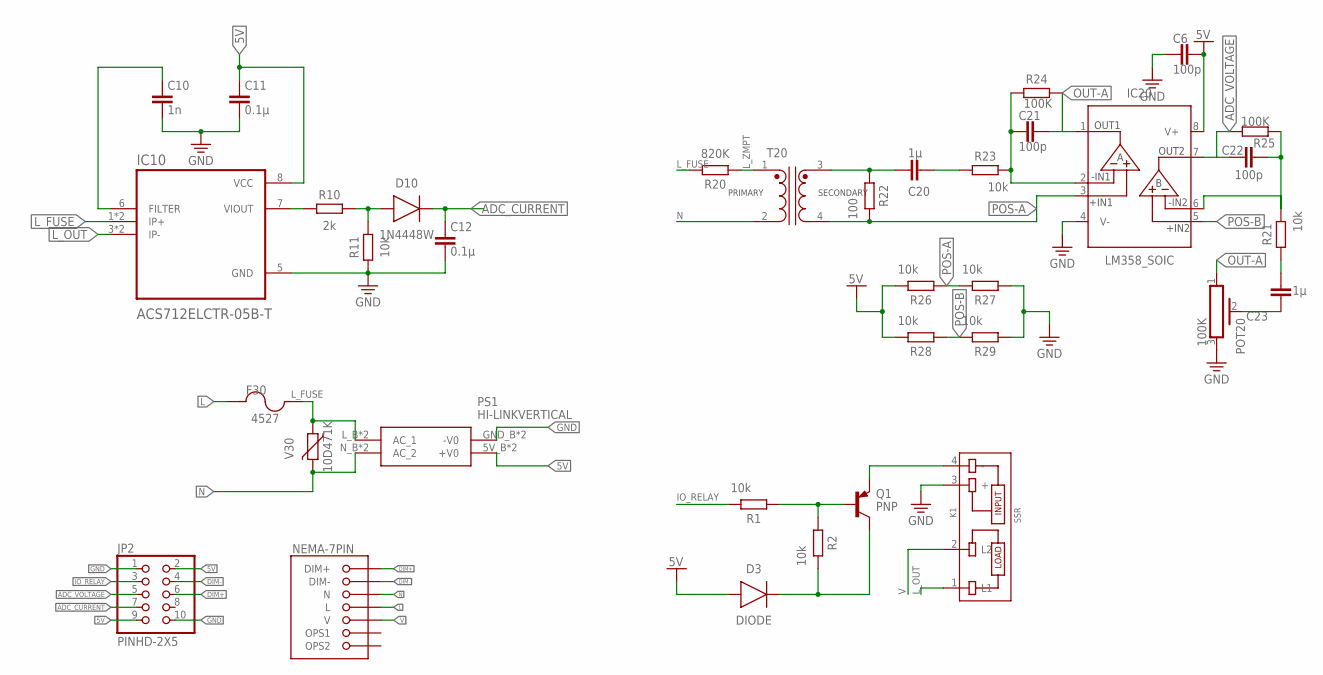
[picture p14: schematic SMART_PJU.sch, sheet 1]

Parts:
C6, C21, C22: 100p; CAPC1608X85
C10: 1n; CAPC1608X85
C11: 0.1μ; CAPC1608X85
C12: 0.1µ; CAPC1608X85
C20, C23: 1µ; CAPC1608X85
D3: DIODE; DIOM5226X290N
D10: 1N4448W; SOD3715X135
F30: 4527
IC10: ACS712ELCTR-05B-T; SOIC127P600X175-8N@1
IC20: LM358_SOIC; SOIC127P600X175-8N
JP2: PINHD-2X5; 2X05
K1: SSR; SSR_G3MB-202P
NEMA-7PIN: NEMA-7P
POT20: 100K; PV36W
PS1: HI-LINKVERTICAL; AC-DC_3.5W(VER)
Q1: PNP; SOT95P237X112-3N
R1, R2, R11, R21, R23, R26, R27, R28, R29: 10k; RESC1608X60
R10: 2k; RESC1608X60
R20: 820K; R0805
R22: 100; R1206
R24, R25: 100K; RESC1608X60
T20: ZMPT101B
V30: 10D471K; MOV-10D561

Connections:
5V: C6.2, C11.1, D3.2 (A), IC10.8 (VCC), IC20.8 (V+), JP2.2, JP2.9, PS1.5V_B (+V0), PS1.5V_T (+V0), R26.2, R28.2; also elsewhere on the board
ADC_CURRENT: C12.1, D10.1 (C), JP2.7; also elsewhere on the board
ADC_VOLTAGE: JP2.5, R25.2; also elsewhere on the board
DIM+: JP2.6, NEMA-7PIN.DIM+; also elsewhere on the board
DIM-: JP2.4, NEMA-7PIN.DIM-; also elsewhere on the board
GND: C6.1, C10.2, C11.2, C12.2, IC10.5 (GND), IC20.4 (V-), JP2.1, JP2.10, K1.3 (+), POT20.3, PS1.GND_B (-V0), PS1.GND_T (-V0), R11.1, R27.1, R29.1; also elsewhere on the board
IO_RELAY: JP2.3, R1.2; also elsewhere on the board
L: F30.1, NEMA-7PIN.L
L_FUSE: F30.2, IC10.1 (IP+), IC10.2 (IP+), PS1.L_B (AC_1), PS1.L_T (AC_1), R20.2, V30.1
L_OUT: IC10.3 (IP-), IC10.4 (IP-), K1.1 (L1)
L_ZMPT: R20.1, T20.1
N: NEMA-7PIN.N, PS1.N_B (AC_2), PS1.N_T (AC_2), T20.2, V30.2
unnamed: C20.1, R22.1, T20.3
unnamed: C21.2, IC20.1 (OUT1)
unnamed: C20.2, R23.1
unnamed: IC10.7 (VIOUT), R10.1
unnamed: C22.1, IC20.7 (OUT2)
unnamed: C21.1, IC20.2 (-IN1), R23.2, R24.1
unnamed: D10.2 (A), R10.2, R11.2
unnamed: C10.1, IC10.6 (FILTER)
unnamed: D3.1 (C), Q1.3 (C), R2.2
unnamed: Q1.1 (B), R1.1, R2.1
unnamed: K1.4 (-), Q1.2 (E)
unnamed: C22.2, IC20.6 (-IN2), R21.2, R25.1
unnamed: C23.2, R21.1
unnamed: C23.1, POT20.2
OUT-A: POT20.1, R24.2
POS-A: IC20.3 (+IN1), R22.2, R26.1, R27.2, T20.4
POS-B: IC20.5 (+IN2), R28.1, R29.2
V: K1.2 (L2), NEMA-7PIN.V

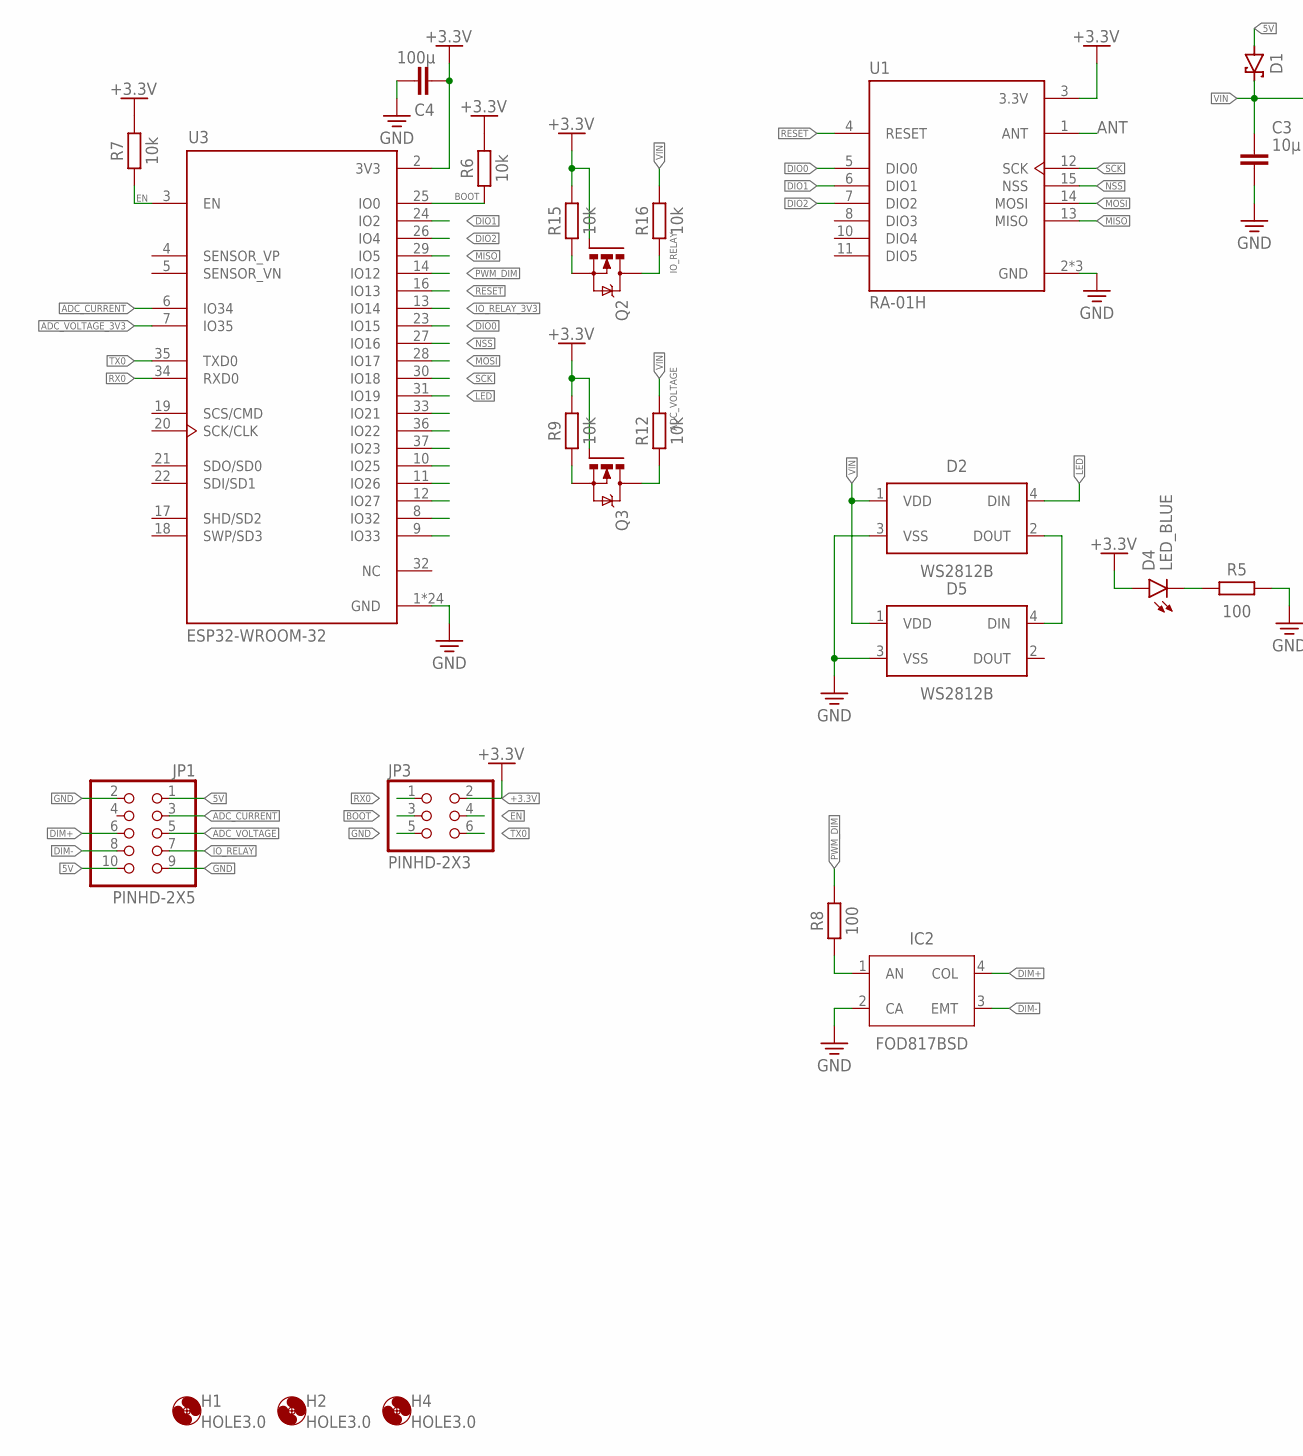
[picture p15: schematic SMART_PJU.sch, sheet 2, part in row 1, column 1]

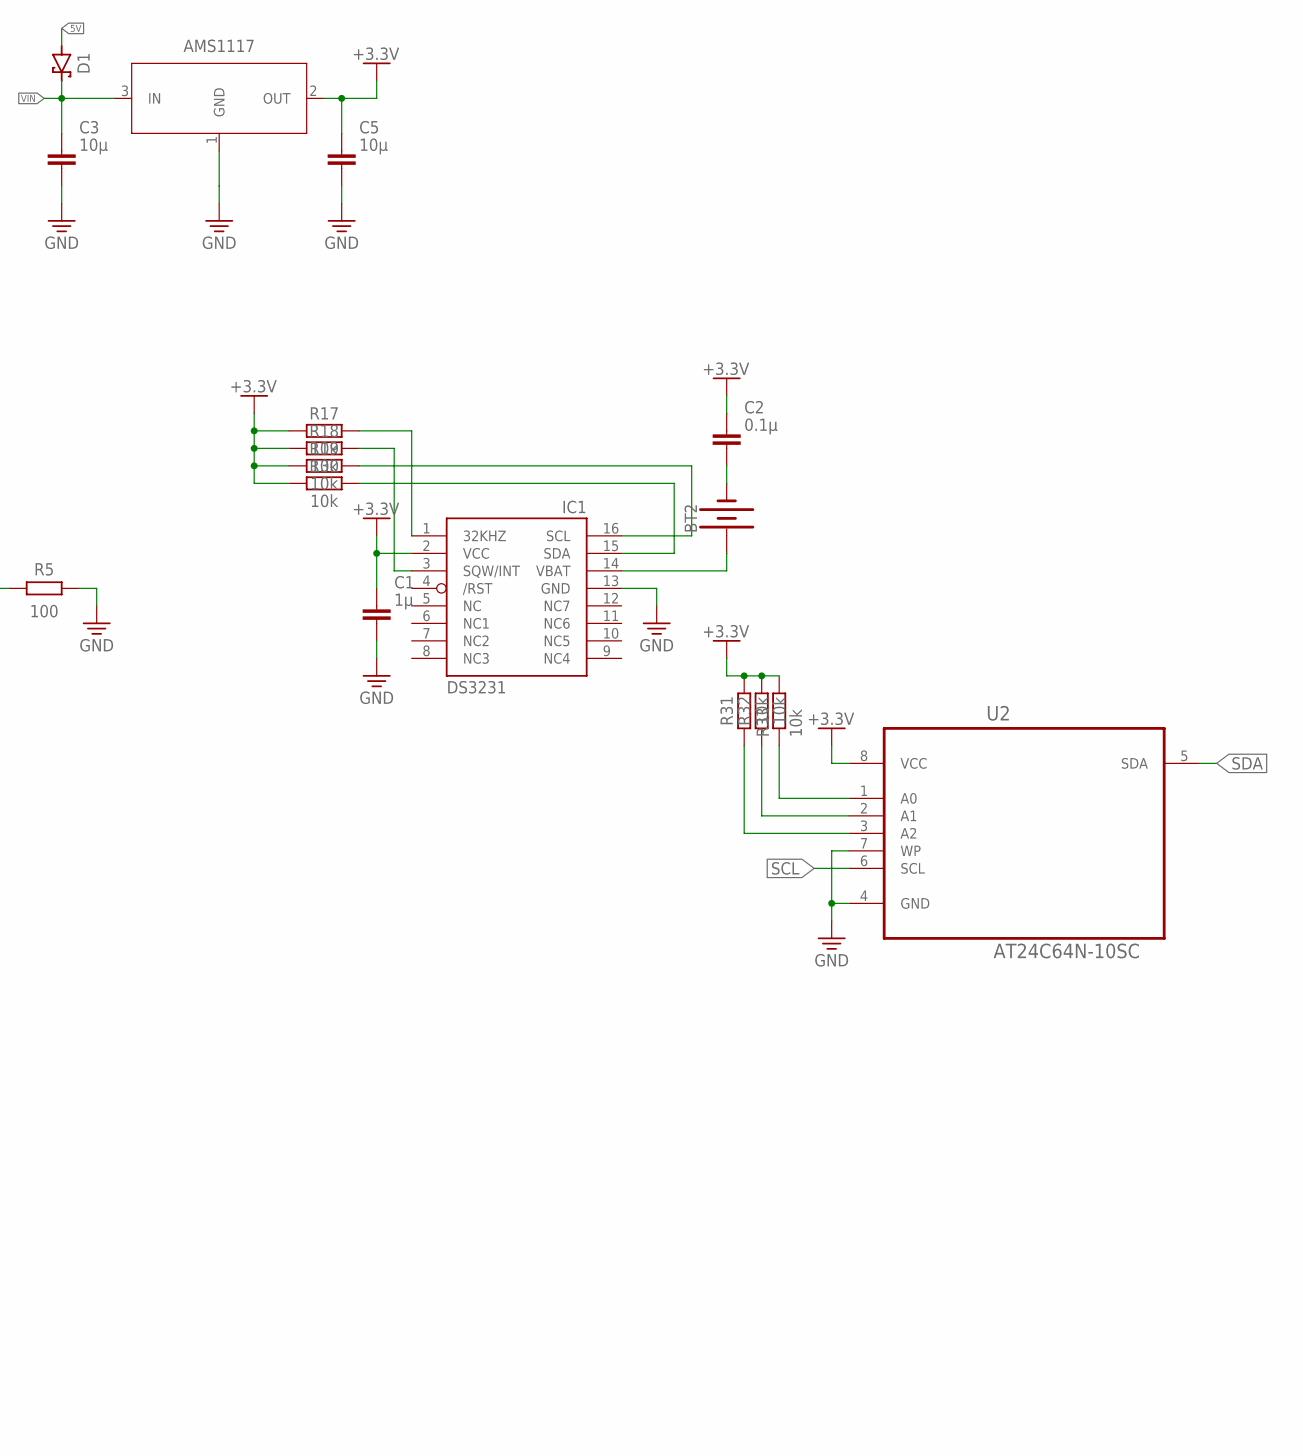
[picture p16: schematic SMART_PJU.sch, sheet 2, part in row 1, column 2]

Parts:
AMS1117: NCP1117ST33T3G; SOT230P700X170-4
BT2: BATTERY-20MM_PTH; BATTCOM_20MM_PTH
C1: 1μ; CAPC1608X85
C2: 0.1μ; CAPC1608X85
C3, C5: 10µ; CAPC1608X85
C4: 100µ; CAPM6032X280
D1: MBR0520LT1G; SODFL3718X115
D2, D5: WS2812B
D4: LED_BLUE; LEDC1608X55N_FLAT-B
H1, H2, H4: HOLE3.0; 3,0
IC1: DS3231/SO; SO16W
IC2: FOD817BSD; DIP1016W60P279L460H460Q4B
JP1: PINHD-2X5; 2X05
JP3: PINHD-2X3; 2X03
Q2, Q3: NMOSFET; SOT23
R5, R8: 100; RESC1608X60
R6, R7, R9, R12, R15, R16: 10k; RESC1608X60
R17, R18, R19, R30, R31, R32, R33: 10k; R1206
U1: RA-01H
U2: AT24C64N-10SC; SOIC127P600X175-8N
U3: ESP32-WROOM-32; MODULE_ESP32-WROOM-32

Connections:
5V: D1.2 (A), JP1.1, JP1.10; also elsewhere on the board
+3.3V: AMS1117.2 (OUT), C1.1, C2.1, C4.1, C5.1, D4.A, IC1.2 (VCC), JP3.2, Q2.1 (G), Q3.1 (G), R6.2, R7.2, R9.2, R15.2, R17.1, R18.1, R19.1, R30.1, R31.2, R32.2, R33.2, U1.3 (3.3V), U2.8 (VCC), U3.2 (3V3)
ADC_CURRENT: JP1.3, U3.6 (IO34); also elsewhere on the board
ADC_VOLTAGE: JP1.5, Q3.3 (D), R12.1; also elsewhere on the board
ADC_VOLTAGE_3V3: Q3.2 (S), R9.1, U3.7 (IO35)
ANT: U1.1 (ANT)
BOOT: JP3.3, R6.1, U3.25 (IO0)
DIM+: IC2.4 (COL), JP1.6; also elsewhere on the board
DIM-: IC2.3 (EMT), JP1.8; also elsewhere on the board
DIO0: U1.5 (DIO0), U3.23 (IO15)
DIO1: U1.6 (DIO1), U3.24 (IO2)
DIO2: U1.7 (DIO2), U3.26 (IO4)
EN: JP3.4, R7.1, U3.3 (EN)
GND: C1.2, C3.2, C4.2, C5.2, D2.3 (VSS), D5.3 (VSS), IC1.13 (GND), IC2.2 (CA), JP1.2, JP1.9, JP3.5, R5.2, U1.2 (GND), U1.9 (GND), U1.16 (GND), U2.4 (GND), U2.7 (WP), U3.1 (GND), U3.15 (GND), U3.38 (GND), U3.39_1 (GND), U3.39_2 (GND), U3.39_3 (GND), U3.39_4 (GND), U3.39_5 (GND), U3.39_6 (GND), U3.39_7 (GND), U3.39_8 (GND), U3.39_9 (GND), U3.39_10 (GND), U3.39_11 (GND), U3.39_12 (GND), U3.39_13 (GND), U3.39_14 (GND), U3.39_15 (GND), U3.39_16 (GND), U3.39_17 (GND), U3.39_18 (GND), U3.39_19 (GND), U3.39_20 (GND), U3.39_21 (GND); also elsewhere on the board
IO_RELAY: JP1.7, Q2.3 (D), R16.1; also elsewhere on the board
IO_RELAY_3V3: Q2.2 (S), R15.1, U3.13 (IO14)
LED: D2.4 (DIN), U3.31 (IO19)
MISO: U1.13 (MISO), U3.29 (IO5)
MOSI: U1.14 (MOSI), U3.28 (IO17)
unnamed: R33.1, U2.1 (A0)
unnamed: R32.1, U2.2 (A1)
unnamed: R31.1, U2.3 (A2)
unnamed: D2.2 (DOUT), D5.4 (DIN)
unnamed: BT2.1 (+), IC1.14 (VBAT)
unnamed: IC1.3 (SQW/INT), R18.2
unnamed: IC1.1 (32KHZ), R17.2
unnamed: BT2.2 (-), C2.2
unnamed: D4.C, R5.1
unnamed: IC2.1 (AN), R8.1
NSS: U1.15 (NSS), U3.27 (IO16)
PWM_DIM: R8.2, U3.14 (IO12)
RESET: U1.4 (RESET), U3.16 (IO13)
RX0: JP3.1, U3.34 (RXD0)
SCK: U1.12 (SCK), U3.30 (IO18)
SCL: IC1.16 (SCL), R19.2, U2.6 (SCL)
SDA: IC1.15 (SDA), R30.2, U2.5 (SDA)
TX0: JP3.6, U3.35 (TXD0)
VIN: AMS1117.3 (IN), C3.1, D1.1 (C), D2.1 (VDD), D5.1 (VDD), R12.2, R16.2

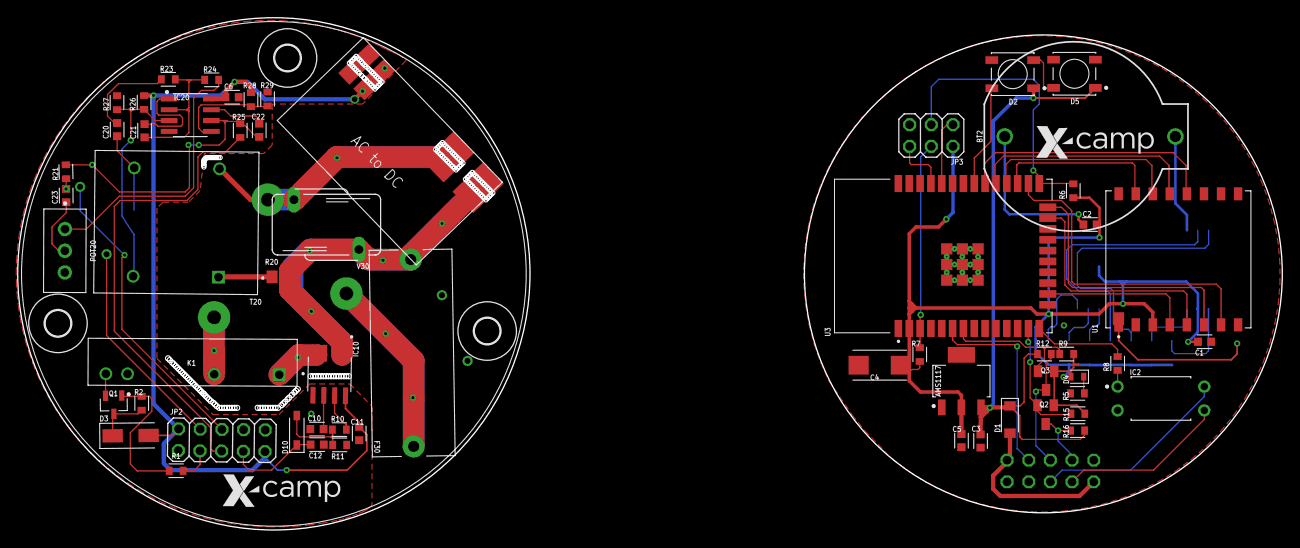
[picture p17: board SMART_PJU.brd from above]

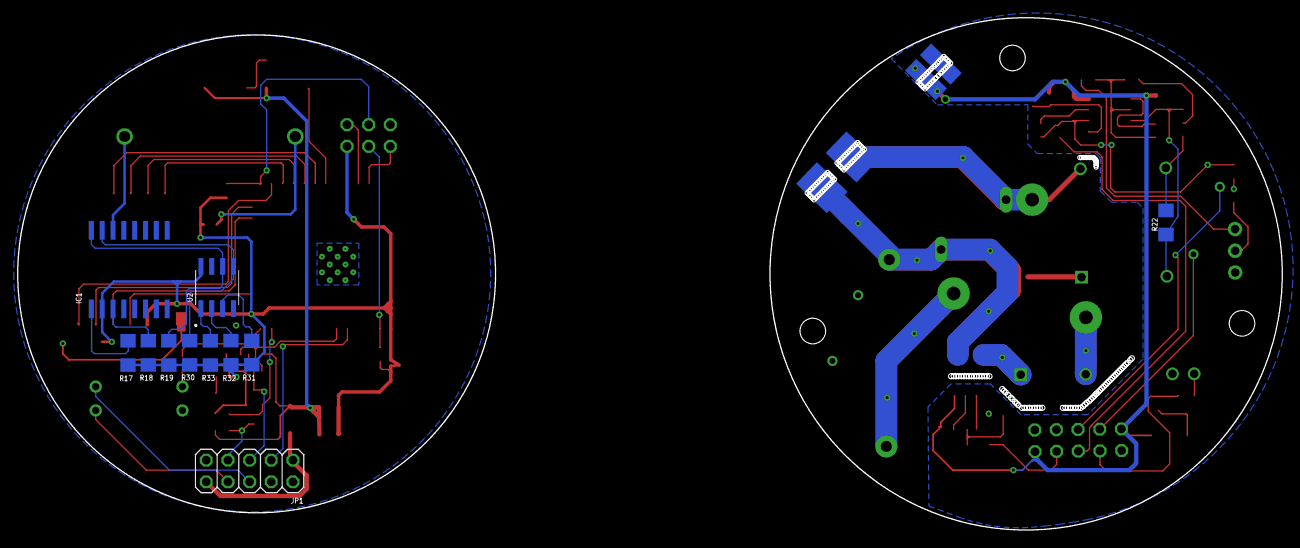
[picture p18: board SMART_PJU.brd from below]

Board: 2 copper layers, 148.2 x 60.0 mm, 73 parts (11 on the bottom side), 60 nets.

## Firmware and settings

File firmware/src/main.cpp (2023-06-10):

#include <Arduino.h>

#include "boards.h"

void setup() {
    // Wait for serial to be ready
    Serial.begin(115200);
    delay(500);

#ifdef VERBOSE
    // wait for serial to be ready
    while (!Serial) {
        delay(1);
    }
#endif

    // initialize the board.
    initBoard();
    DEBUG_PRINTF_TS("[SETUP_1] initBoard() - done\n");

    mySensor.begin();
    DEBUG_PRINTF_TS("[SETUP_2] mySensor.begin() - done\n");

    wsInit();
    DEBUG_PRINTF_TS("[SETUP_3] wsInit() - done\n");

    setupLMIC();
    DEBUG_PRINTF_TS("[SETUP_4] setupLMIC() - done\n");

    Serial.println("[XLKM#4 PJU] Device is Ready for Serial");
}

void loop() {
    loopLMIC();
    mySensor.loop();
    dnsServer.processNextRequest();
}

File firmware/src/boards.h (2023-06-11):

#ifndef BOARDS_H
#define BOARDS_H

#include <ACS712.h>
#include <Arduino.h>
#include <EEPROM.h>
#include <FastLED.h>
#include <RTClib.h>
#include <SPI.h>
#include <Wire.h>
#include <ZMPT101B.h>

// Calibration Data
#define ACS712_ZP 2400
#define VOLTAGE_SENSITIVITY 1200.0f

// EEPROM Address
#define EEPROM_SIZE 512
#define ADDR_CURRENT 0
#define ADDR_VOLTAGE 2
#define ADDR_APPEUI 4
#define ADDR_DEVEUI 12
#define ADDR_APPKEY 20

// Debug printing
#define DEBUG_PORT Serial
#if defined(VERBOSE)
#define DEBUG_PRINTF(...) \
    { DEBUG_PORT.printf(__VA_ARGS__); }
#define DEBUG_PRINTF_TS(...)                                    \
    {                                                           \
        DEBUG_PORT.printf("%d ms: ", osticks2ms(os_getTime())); \
        DEBUG_PORT.printf(__VA_ARGS__);                         \
    }
#else
#define DEBUG_PRINTF(...) \
    {}
#define DEBUG_PRINTF_TS(...) \
    {}
#endif

#include "AP/webserver.h"
#include "LED/led.h"
#include "LoRaWAN/loramac.h"
#include "Sensor/sensor.h"

/* Function */
void initBoard();

/* Pin Mapping */
#define UNUSE_PIN (0)

#ifdef PROTOTYPE

#define I2C_SDA 23
#define I2C_SCL 22

#define SPI_SCLK 5
#define SPI_MISO 19
#define SPI_MOSI 27
#define PIN_NSS 18
#define PIN_RST 23
#define PIN_DIO0 26
#define PIN_DIO1 33
#define PIN_DIO2 32

// Other
#define WS2812B_PIN 14
#define RELAY_PIN 15
#define DIMMER_PIN 13
#define ADC_CURRENT 34
#define ADC_VOLTAGE 35
#define ADC_LIGHT 36
#define LED_BOARD 25

#else

#define I2C_SDA 23
#define I2C_SCL 22

#define SPI_SCLK 18
#define SPI_MISO 5
#define SPI_MOSI 17
#define PIN_NSS 16
#define PIN_RST 13
#define PIN_DIO0 15
#define PIN_DIO1 2
#define PIN_DIO2 4
// Other
#define WS2812B_PIN 14
#define RELAY_PIN 26
#define DIMMER_PIN 27
#define ADC_CURRENT 34
#define ADC_VOLTAGE 35
#define ADC_LIGHT 36
#define LED_BOARD 2

#endif

#endif

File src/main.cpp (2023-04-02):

#include "PJU.h"

ZMPT101B voltageSensor(ADC1_PIN);
ACS712 currentSensor(ACS712_30A, ADC2_PIN);

struct sensor sensor_data {
    .temperature = 25,
    .voltage = 220,
    .current = 500,
    .light = 40,
    .time = DateTime(2023, 03, 19, 12, 30, 00)
};

unsigned long lastSend_1 = 0;
unsigned long lastSend_2 = 0;
unsigned long lastSend_3 = 0;

void setup() {
    initBoard();
    initWiFiPoint();

    pinMode(ADC1_PIN, INPUT);
    pinMode(ADC2_PIN, INPUT);

    voltageSensor.setVref(3.3);

    voltageSensor.calibrate();
    currentSensor.calibrate();

    Serial.println("[XLKM#4 PJU] Device is Ready for Serial");
    setupLMIC();
}

void loop() {
    loopLMIC();

    server.handleClient();

    sensor_data.time = rtc.now();
    sensor_data.temperature = rtc.getTemperature();
    sensor_data.voltage = voltageSensor.getVoltageAC();
    sensor_data.current = currentSensor.getCurrentAC();
    sensor_data.light = map(analogRead(ADC1_PIN), 0, 4000, 0, 100);

    unsigned long currentMillis = millis();
    if (currentMillis - lastSend_1 >= 2000) {
        lastSend_1 = currentMillis;

        char buffer[256];
        snprintf(buffer, sizeof(buffer), "[Sensor] %d-%d-%d | %d:%d:%d | %.2f °C | %.2f V | %d mA | %d %%",
                 sensor_data.time.year(),
                 sensor_data.time.month(),
                 sensor_data.time.day(),
                 sensor_data.time.hour(),
                 sensor_data.time.minute(),
                 sensor_data.time.second(),
                 sensor_data.temperature,
                 sensor_data.voltage,
                 sensor_data.current,
                 sensor_data.light);
        Serial.println(buffer);
    }

    if (currentMillis - lastSend_2 >= 25) {
        lastSend_2 = currentMillis;

        FastLED.show();
        digitalWrite(BOARD_LED, !digitalRead(BOARD_LED));
    }

    if (currentMillis - lastSend_3 >= 10) {
        lastSend_3 = currentMillis;

        // // Zero point (Without power input)
        // int Z = voltageSensor.calibrate();

        // // Zero point (With power input)
        // int ZL = voltageSensor.calibrateLive();

        // // Zero point voltage (With or without power input)
        // float ZV = voltageSensor.calibrateVoltage();

        // if (Z <= (ZL + 3) && Z >= (ZL - 3)) {
        //     Serial.print(String("| ") + Z);
        // } else {
        //     Serial.print(String("| ---"));
        // }
        // Serial.print(String(" | ") + ZL);
        // Serial.println(String(" |") + ZV + "V|");
    }
}

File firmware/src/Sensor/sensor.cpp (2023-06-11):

#include "sensor.h"

#include "../boards.h"

TwoWire I2C_RTC = TwoWire(0);
DateTime datetime;

void cSensor::begin() {
#ifdef DUMMY_DATA
    return;
#endif
    I2C_RTC.begin(I2C_SDA, I2C_SCL, 100000);
    rtc.begin(&I2C_RTC);

    uint16_t currentZP = EEPROM.readUShort(ADDR_CURRENT);
    uint16_t voltageSensitivity = EEPROM.readUShort(ADDR_VOLTAGE);

    acs712.setZeroPoint(currentZP);
    zmpt101b.setSensitivity(voltageSensitivity);
    pinMode(ADC_LIGHT, INPUT);
}

void cSensor::loop() {
    auto const tNow = millis();
    auto const deltaT = tNow - this->m_lastUpdate;
    static bool prevStatus;
    static uint8_t prevDimmer;

    // Check if data is not same as previous
    if (prevDimmer != dimmer) updateDimmer();
    prevDimmer = dimmer;

    if (prevStatus != status) updateStatus();
    prevStatus = status;

    if (deltaT >= 5000) {
        this->m_lastUpdate = tNow;
        led2.setOffAfter(CRGB::Orange, 500);

        unix_time = getUnixTime();
        temperature_deg_c = getTemperature();
        voltage_v = getVoltage();
        current_m_a = getCurrent();
        light_level = getLightLevel();

        printData();
    }

    // // Schedule on-off power
    // if (datetime.second() % 2 == 0) {
    //     // Serial.printf("Minute Even : %d\n", datetime.second());
    //     turnRelay(true);
    // } else {
    //     // Serial.printf("Minute Odd : %d\n", datetime.second());
    //     turnRelay(false);
    // }
}

// Get Device AC Voltage
uint8_t cSensor::getVoltage(void) {
#ifdef DUMMY_DATA
    const uint8_t voltage = random(215, 225);
#else
    const uint8_t voltage = zmpt101b.getRmsVoltage();
#endif

    return voltage;
}

// Get Device AC Current
uint16_t
cSensor::getCurrent(void) {
#ifdef DUMMY_DATA
    const uint16_t current = random(800, 1500);
#else
    const uint16_t current = acs712.getCurrentAC() * 1000;
#endif

    return current;
}

// Get Device Unix Time
uint32_t
cSensor::getUnixTime(void) {
#ifdef DUMMY_DATA
    uint32_t unixtime = 1686456495 + (millis() / 1000);
#else
    // Get current time
    datetime = rtc.now();
    uint32_t unixtime = datetime.unixtime();
#endif

    return unixtime;
}

// Get temperature (Stub)
float cSensor::getTemperature(void) {
#ifdef DUMMY_DATA
    float temperature = random(20, 30);
#else
    float temperature = rtc.getTemperature();
#endif

    return temperature;
}

// Get Light Level
uint8_t cSensor::getLightLevel(void) {
#ifdef DUMMY_DATA
    uint8_t lightLevel = random(0, 100);
#else
    // Convert to percentage
    uint8_t lightLevel = map(analogRead(ADC_LIGHT), 0, 4095, 0, 100);
#endif

    return lightLevel;
}

// Turn PJU On/Off
void cSensor::updateStatus() {
    if (status)
        dimmer = 100;
    else
        dimmer = 0;

    uint8_t dim_8bit = dimmer == 100 ? 0 : 255;
    ledcWrite(0, dim_8bit);

    DEBUG_PRINTF("[SENSOR] Status Changed to %d\n", status);
}

// Update PJU Dimmer
void cSensor::updateDimmer() {
    if (!status) return;

    uint8_t dim_8bit = map(dimmer, 0, 100, 255, 0);
    ledcWrite(0, dim_8bit);

    DEBUG_PRINTF("[SENSOR] Dimmer Changed to %d\n", dimmer);
}

// Print Sensor Data
void cSensor::printData(void) {
    // Print Data Sensor
    DEBUG_PRINTF("[SENSOR] ESP32: %.1f°C | Time = %d | %d V | %d mA | %.1f°C | %d Lux | Status = %d | Dimmer = %d\n",
                 temperatureRead(), unix_time, voltage_v, current_m_a, temperature_deg_c, light_level, status, dimmer);
}

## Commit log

2023-03-19 feat : sensor, access point done
2023-03-22 feat : led indicator
2023-03-22 feat : freeRTOS on led
2023-03-23 fix : benerin led fade dan blink
    [boards.cpp, loramac.cpp, main.cpp]
2023-04-26 include hardware
    [BOM.xlsx, BOM_power.xls, PnP_power.xls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]
2023-05-09 failed arduino lorawan
2023-05-12 update hardware
    [SMART_PJU.brd, SMART_PJU.sch]
2023-05-12 schematic change
    [SMART_PJU.brd, SMART_PJU.sch]
2023-05-12 checkpoint controller
    [BOM_power.xls, PnP_power.xls, controller.brd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]
2023-05-14 bakcup before ganti ukuran smd
    [controller.brd, controller.sch, power.brd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]
2023-05-14 checkpoint sebelum cetak single layer
    [controller.brd, controller.sch, power.brd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]
2023-05-16 feat : checkpoint 2
    [BOM.xlsx, SMART_PJU.brd, SMART_PJU.sch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]
2023-05-19 Merge commit 'ad2010fd0a1d412e2901b50e6cc7a45f280bb39c' into dev
    # Conflicts:
    # README.MD
    # README.md
    # REAME.md
    [power.brd]
2023-05-19 fix : 2 layer pcb, dim pin terhalang
    [controller.sch, power.brd, power.sch]
2023-05-21 checkpoint 21/05
    [controller.brd, controller.sch, power.brd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]
2023-05-26 feat : react to esp32 script
    [controller.brd, partitions.csv, power.brd]
2023-05-30 feat : checkpoint for interface dev 👾
    [controller.brd, controller.sch]
2023-06-04 fix : dim control, lora message decoder 🎐
    [boards.cpp, boards.h, loramac.cpp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]
2023-06-05 feat : preferences new lib 🆕
2023-06-05 for test 🧪
2023-06-05 fix : error lmic
    [main.cpp]
2023-06-11 feat : EEPROM 💿

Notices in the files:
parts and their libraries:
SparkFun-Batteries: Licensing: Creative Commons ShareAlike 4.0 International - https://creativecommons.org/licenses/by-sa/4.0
